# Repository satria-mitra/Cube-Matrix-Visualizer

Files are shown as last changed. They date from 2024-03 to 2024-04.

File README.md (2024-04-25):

# Cube-Matrix Visualizer

<p align="center">
  
</p>

To see how Cube Matrix works, please visit our [youtube channel](https://www.youtube.com/watch?v=XeQNfcWp1Bc)

## What is Cube-Matrix Visualizer?

Cube-Matrix Visualizer creatively connects the fields of IoT (Internet of Things) technology and art, aiming to create a data visualization device that meets the complex needs of contemporary society. Currently, the device focuses on reacting to changes in humidity, temperature and carbon dioxide concentration with a series of artistic LED animations. In the future, the team will provide OTA (over-the-air) services to upgrade the functionality of the device and enable broader data visualization through more captivating animations.

## Why is Cube-Matrix Visualizer Useful? 

In an era oversaturated with data, the Cube-Matrix Visualizer emerges as a beacon of innovation, merging the practicality of IoT technology with the sublime beauty of art. This fusion presents a unique advantage: making data not only accessible but also aesthetically pleasing, transforming mundane statistics into captivating visual stories.

### Artistry and Technology Combined

The Cube-Matrix Visualizer stands apart through its artistic approach to data visualization. Each LED animation is meticulously crafted, not just for clarity, but to evoke emotion and appreciation for the beauty inherent in data. The device acts as a living canvas, where pixels of light paint the ever-changing tapestry of our environment's data.

### Tailored to the Modern Aesthetic

Designed with modern sensibilities in mind, the Cube-Matrix Visualizer is more than a functional device—it's a piece of art that complements any space. Its sleek design and dynamic visual output offer a dual function: enhancing room aesthetics while providing valuable environmental insights. It's an innovative way to integrate technology into our lives without sacrificing style or comfort.

### Engaging Visual Experience

Beyond mere decoration, the Cube-Matrix Visualizer engages its users on a sensory level. The visualizations are designed not only to inform but to mesmerize, creating an immersive experience that turns data observation into a moment of zen. It encourages users to interact with and reflect on their environmental conditions, fostering a deeper connection between the user and their surroundings.

### A Canvas for Future Possibilities

The promise of OTA updates opens a realm of future possibilities, where the device's artistry and functionality evolve together. New data visualizations can be introduced, offering fresh perspectives and insights, and keeping the user's experience vibrant and current. This commitment to growth ensures that the Cube-Matrix Visualizer remains not only a tool for today but a lasting piece of art that continues to enrich lives.

## Market analysis

We are a small independent entrepreneurial company. Our product is an LED cube system that can visualize the air quality data (including CO2 concentration, temperature, humidity) collected by the sensor using an animation played by the LED cube.  This system uses an independent power supply and a wide voltage design, and can be used directly in most areas of the world. Users can use the buttons on the product base to switch animation modes and display different data. The cost of our product, without taking into account labor costs, is 126 pounds. It takes 24 hours of work for this team member to complete this product. If you consider London wage standards, the total cost is approximately 366 pounds, which is what we need solved problem.
Our target market is technology enthusiasts, education fields, and high-consumption groups. Our products will be crowdfunded on kickstarter.
Our opponents mainly fall into two categories. One is traditional LED cube kits, which are cheaper but cannot provide air quality detection functions. At the same time, they rarely sell finished products, which poses challenges to users’ technical capabilities and time. In addition, such products do not have the ability to interact with users. The other category is traditional air quality detectors, with similar accuracy, they are also cheaper, but they do not have furniture/decoration capabilities and lack the artistic expression of this product.
We will also provide free ota services to crowdfunding users to ensure the rights and interests of crowdfunding users.
Our current market areas are Europe and North America.

### SWOT.
- Advantage
LED CUBE with integrated air quality detection is a pioneering solution in the technology market, offering the dual functionality of air quality detection and visual display via an LED cube. This fusion of innovations not only differentiates the product but also captures a niche market consisting of technology enthusiasts, the education sector and high-spending groups. A significant advantage of this product is that users can interact with the product by changing animation modes and displaying various data, thus enhancing the overall user experience. Additionally, providing over-the-air (OTA) updates to crowdfunding users signifies our commitment to product longevity and customer satisfaction.

- Weakness
Conversely, the product's market penetration may be hampered by its high production costs (approximately £366), placing it in a higher price range, which may limit its acceptance by a wider audience. The production process for each unit requires 24 hours of labor, which not only drives up costs and selling prices, but also cuts production capacity. Furthermore, relying on crowdfunding to enter the market creates financial uncertainty, as access to funds in this way depends on the dynamics of crowdfunding platforms and investor interest.

- Opportunities
As people's living standards improve, people's awareness and concern about air quality in residential and office environments continues to grow, providing important opportunities for market expansion. By finding foundries to reduce costs and selling prices, and upgrading product features, these measures will tap a wider audience and stimulate market growth. Strategic alliances with educational institutions or environmental organizations can open up new avenues of market penetration and enhance brand credibility.

- Threaten
Although this product has good prospects, it still faces severe competition. These threats come from traditional LED cube kits and air quality detectors, which despite their limited functionality compared to the author's team's products, appeal to consumers through lower prices. Additionally, there is a risk that a saturation of similar products with imitators may dilute the uniqueness of the product. Economic fluctuations further exacerbate these threats, as a recession may reduce the disposable income of high-spending groups and reduce their interest in purchasing such products.

In addition, this group introduces value chain analysis here. Through the exploration of main activities and supporting activities, this analysis describes how to add value and minimize costs, thereby enhancing the product's competitive advantage in the global market.

### Main activities
-Inbound logistics
The initial stage of the value creation process: procuring high-quality sensors and LEDs from reputable suppliers to ensure product quality. At the same time, efficient inventory management is required to minimize storage costs and avoid stock-outs, thereby maintaining a seamless production process.

-Operations
The assembly of the LED cube system is a critical operation. The development of custom firmware for animated data display is at the heart of the product's uniqueness. Strict quality assurance processes are also implemented to meet the safety and performance standards of the regions in which they are sold.

-Outbound logistics
Strategic packaging of products not only ensures their protection during transportation, but also focuses on an environmentally friendly ethos. Logistics partners are selected with a focus on reliability and cost-effectiveness to facilitate global delivery capabilities.

-Marketing and Sales
Use social media, technology blogs and online forums to engage digital marketing strategies to attract the interest of technology enthusiasts and the education sector. Prepare your Kickstarter campaign carefully, aiming to emphasize the product's unique value proposition while seeking partnerships with educational institutions and environmental organizations to increase awareness of the product.

-Serve
Increase customer satisfaction and product longevity by providing after-sales support with comprehensive customer service for setup, usage and troubleshooting, as well as OTA updates for firmware enhancements and feature additions.

### Support activities
-Purchase
Negotiations with suppliers have a dual goal: to secure the best price without compromising quality, and to work with suppliers who can support scalable solutions as volumes increase.

-Technology development
The commitment to ongoing research and development is evident, with the goals of improving product performance, reducing production costs and incubating new features. Software development investments are aimed at refining the user interface and expanding functionality.

-Human resource Management
We are committed to training our teams in efficient production techniques and exemplary customer service, cultivating a culture full of innovation and continuous improvement.

-Infrastructure
The management of the overall operating structure focuses on financial management, legal support and administrative functions. We envisioned a scalable infrastructure capable of adapting to growing business needs, such as flexible IT systems and workspaces.

### Identify areas for improvement and cost reduction
Operational efficiency is targeted to improve, with potential strategies including automation and improved assembly techniques to reduce significant production time. Production scaling is considered a means to exploit economies of scale, thereby reducing unit costs and enhancing market competitiveness. Diversification of the supplier base is recommended to reduce risk and possibly cost through competitive sourcing. In addition, digital marketing efforts will be strengthened to use analytics as a tool to increase focus on ideal customer segments to optimize conversion rates.

## Getting Started

The Cube-Matrix Visualizer is available as a finished product. To get started:

1. Place an order and inspect the product upon arrival to ensure it's in good condition.
2. Connect the device to a power source. It's designed to support a wide range of voltages, making it accessible to users in various locations without the need for additional transformers. However, users with specific electricity requirements should use appropriate converters.
3. Once powered, the Cube will activate. Please allow a brief period for its sensors to adjust to optimal working conditions.
4. To cycle through different LED animations, simply press the button located on the front base of the device. Animations will change in sequence.

Now, you can assemble your own Cube-Matrix. To make your own cube, please follow the steps below:

1. Clone the Repository: git clone https://github.com/satria-mitra/Cube-Matrix.git
2. Hardware Setup: Assemble the Cube Matrix using the provided list of components and assembly instructions found in the Hardware folder.
3. Software Configuration: Navigate to the Software folder and follow the setup instructions to install necessary libraries and upload the code to your microcontroller.
4. Running Cube Matrix: Power up the device and use the button interface to toggle between different environmental data visualizations.

**Cube making steps**  
1. Use 3D printer to print two solder holders（solder holders/Holder-3.stl）.
   微信图片_20240424061742
3. Splice the two holders together, place the rgb LED on the holder and solder the data pin (data in to data out) between the two LEDs.
   LED schematic
4. Cut and straighten the copper wire and place the copper wire on the groove of the holder,then solder rgb led and copper wires according to the schematic diagram to make eight led layers, and power up to test each layer.
   微信图片_20240424062415
6. Laser cut four cube holders, then use the holders to support the layers to build the cube and solder the ground, power and data pins for each layer（Pay attention to the data pin connection method of each layer, data in must be connected to data out.）.
   微信图片_20240424062532
8. Use Adafruit Feather M0 Doard to connect the cube, connect the ground and power supply normally, and connect the data in of the bottom layer to the D6 pin of the board.
9. Upload the (Scripts/Final_code/Cube_Final.ino)code to the board, and the cube will display three animations in a loop.

## Getting Help

Owners of the Cube-Matrix Visualizer will receive a comprehensive manual detailing operational guidance and troubleshooting tips. Further assistance is available through several channels:

- **Email Support:** For direct inquiries, contact our customer service at Cube-Matrix-Visualizer@gmail.com.
- **GitHub Repository:** Feel free to post questions or feedback in the issues section of our GitHub repository.
- **Future Online Support:** We plan to launch a dedicated website offering an enhanced support function for an improved user experience.

For more direct assistance, you can also reach out to our team members via GitHub profiles linked in the Contributors section

## Contributors
Cube Matrix is maintained and contributed to by a dedicated team of students from the Connected Environments course at CASA. Our team members are
1. [Satria Utama ](https://github.com/satria-mitra)
2. [Guandi Chen](https://github.com/grandy0831)
3. [Huanchao Hong](https://github.com/ChaceHH-H)
4. [Zekun Wang](https://github.com/AntiRain114)

## Design, Development, and Execution
The Cube Matrix project started as an inspiration from a basic LED cube project, evolving into a sophisticated tool for visualizing environmental quality. The project's development journey, from the initial 5x5x5 cube prototype to the advanced 8x8x8 design, showcases our commitment to innovation and user-centric design.  

## Key Features
Environmental Monitoring: Measures temperature, humidity, and CO2 levels.
Dynamic Visual Display: Uses animations to display IEQ data, making it intuitive.
Educational Tool: Helps users understand the impact of IEQ on health and well-being.
For a comprehensive overview of the design process, technical challenges, and our solutions, please refer to the Documentation folder, which includes detailed design documents and technical drawings.

## License
This project is licensed under the MIT License - see the LICENSE file for details.

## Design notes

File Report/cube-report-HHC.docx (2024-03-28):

原计划的缺点

（原计划led的图片）

（原计划动画的设计图片）

We showed our initial plan at the first Group Crit, using common anode RGB LEDs to make a 5*5*5 RGB cube, using SCD-30 to read three kinds of data, and use one animation to display the temperature, humidity and CO2 data at the same time. The week after Group Crit we tried making and soldering some LEDs, but then we discovered the disadvantages of using common anode RGB LEDs: The common anode RGB LED uses three GPIO pins to control the brightness of red, green, and blue colors. This means that if we want to individually control the color of each LED in the cube, each LED requires three motherboard GPIO pins. So we must use additional hardware (such as shift registers or LED drivers) to expand the GPIO pins. Even a small cube of 5*5*5 will require dozens of registers and hundreds of resistors, which will cause Circuit design has become very complicated, whether it is LED welding or PCB design, it is not an easy task. And we also found the 5*5*5 cube to be too small at 125 LEDs, which limits the level of detail in the animation that the cube can show, and fewer LEDs means that fewer pixel points are changing at any given time, which can result in animations that don't look smooth or coherent. Less 3D space is provided, which limits creativity in spatial animation.

计划变动

（APA106 pin脚图片）

So after careful consideration, we changed our plan during reading week. Our new plan use APA106, which is addressable RGB LED with built-in controller IC and register, each LED only need one wire to connect data in pin to motherboard GPIO pin to control the colour, so we don't need any register and other Components, compared to common RGB LEDs, it is much easier to use and build, greatly simplifying the circuit, we only use three jumpers to control hundreds of rgb led, and also allows us to easily build larger rgb cube.

In addition, we upgraded the cube to 8*8*8, using 512 LEDs, compared to 5x5x5 with 125 LEDs, which can display more complex and detailed images and animations, providing a richer visual experience. The larger 3D space allows for more complex animation effects to be achieved in a three-dimensional space. This increased spatial dimension provides more possibilities for designing animations that allow for more animation effects to be explored with respect to light and shadow, depth and perspective. The new plan changed from showing three pieces of data in one animation to designing a separate animation for each piece of data, as we found that showing three pieces of data at the same time would make it difficult to understand and get the visualisation of the data from the animation.

制作步骤

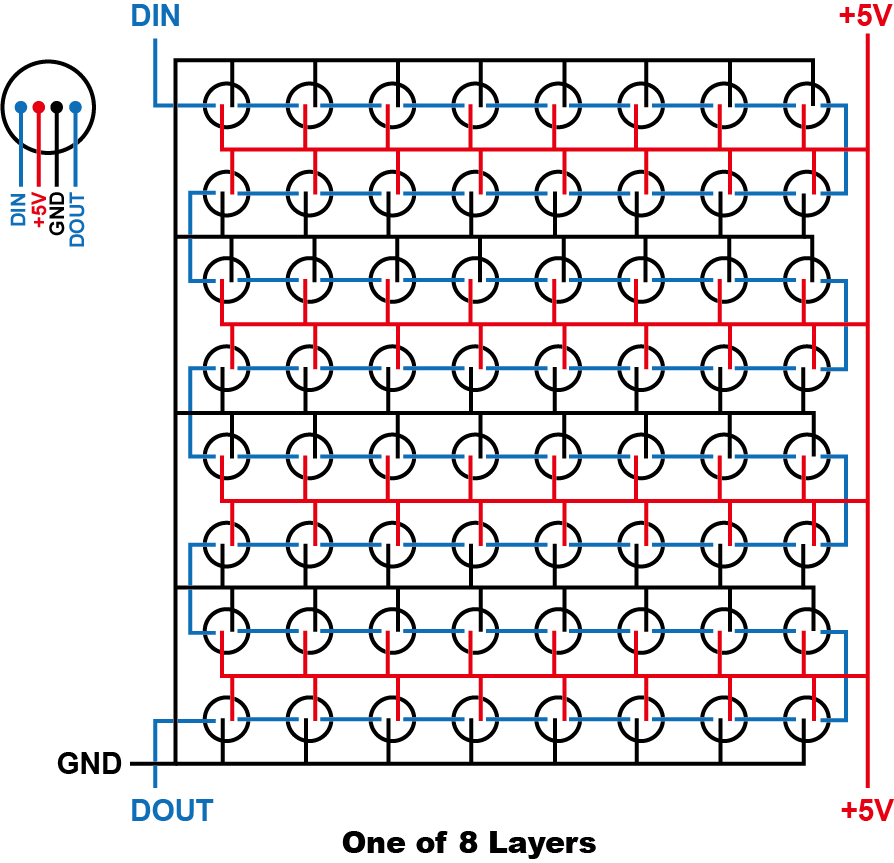
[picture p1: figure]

We first designed the wiring of the cube, our design is to divide the cube into eight 8*8 led layers, each layer is actually a strip of 64 leds as shown in the figure, because the APA106 has a built-in controller IC and uses the same protocol as the WS28 LEDs, we can make it an rgb strip by connecting the data of the previous led data out to the data in of the next led to connect the led in series and make it a rgb strip. As shown in the picture, the blue line is the data pin which connects all the LEDs in series, the black and red lines are the ground and power supply, all the LEDs share the ground and power supply.

（holder 的图片）

Next we weld layer, in order to ensure that the welding neat and beautiful, we first 3d printed 3 welding holder, holder on the holes reserved for placing the led and wire, we first put the leds into the holes, will be welded in series with the led's data pin, and then use the straightened copper wire as the power rail welding grounding and power supply.

（layer通电的图片）

We soldered 8layers and powered up to check if eachlayer is soldered correctly, tested to control the rgb colour using the test code, the APA106 supports the same protocol as the WS28 LEDs, so we used Adafruit_NeoMatrix and NeoPixel to control the colour and brightness of the led.

（cube图片）

After soldering eight layers, we stacked the layers on top of each other and soldered the data pins between them to make the layers into a long strip of 512 leds, which of course look like cubes in appearance. we used the SCD-30 to take readings of temperature, humidity and co2 and connected the sensors and the cube to the feather M0 board.

代码

After completing the cube assembly, we started writing the animation code. Since the cube is actually a strip of lights on the circuit connections, we use the Adafruit_NeoMatrix library to simulate the led strip as a cube, this will reassign the coordinates of the leds and allowing us to write the animation more easily, and then use the Adafruit_NeoPixel library to control the led colours.

（led函数图片）

There are a couple of key functions in the code, one for lighting up the led, led() takes the coordinates and colours it receives and then uses NeoPixel library commands to control the lighting of the led.

（color数组和函数图片）

We put the rgb values of commonly used colours into the color array to be used to change colours more easily. When used, the GetColor() function assigns the rgb values to the NeoPixel library colour command.

（按钮函数）

Our cube has a button to toggle the animation, and the button is called using attachInterrupt() so that the button can be detected in real time while the animation function is running, and all the animation functions will detect when the button's state changes by checking to see if the button is break; or return;, to skip the rest of the function that is not executed in order to to toggle the animation on-the-fly.

We have four animation functions, three for data visualisation and one for numeric and alphabetic animation to display the data. The code structure of the animation functions is actually quite simple, we make extensive use of for and while statements, and use the led() function in a loop to change the coordinates and colour of the lit led to compose the animation. The most difficult part was designing the coordinates of the led in each loop, and we spent a lot of time testing and envisioning the logic of the led changes.

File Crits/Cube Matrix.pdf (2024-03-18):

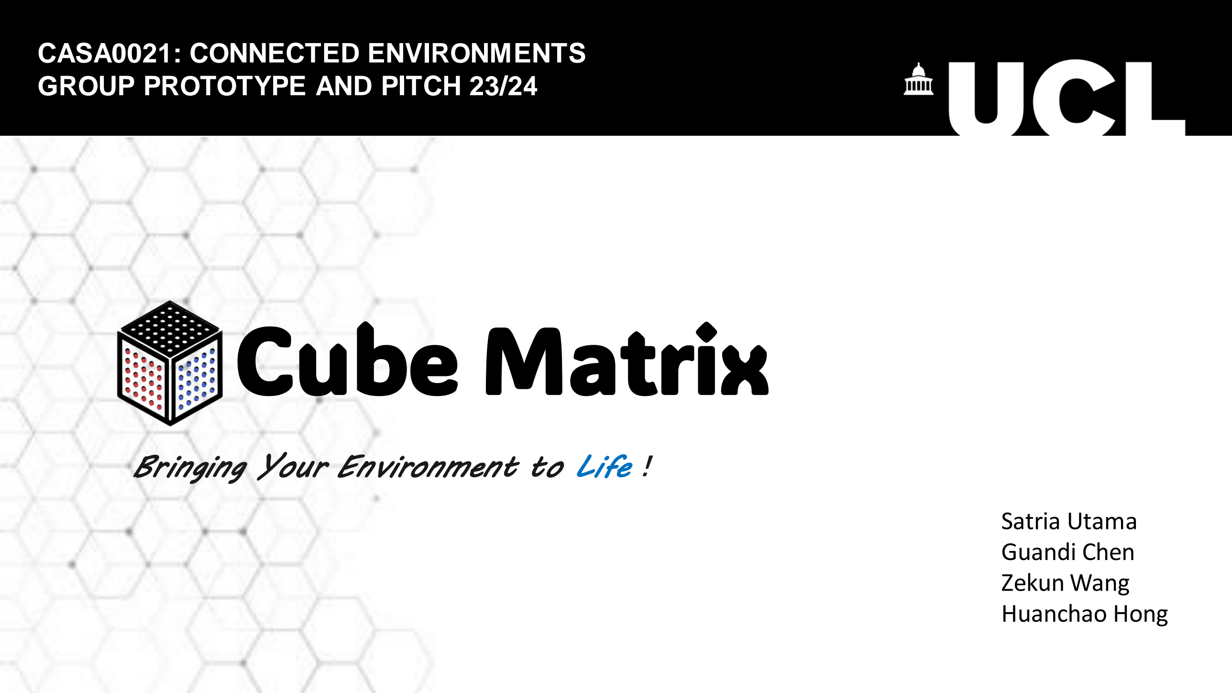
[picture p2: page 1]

# Cube Matrix

Bringing Your Environment to Life！

Satria Utama
Guandi Chen
Zekun Wang
Huanchao Hong

CASA0021: CONNECTED ENVIRONMENTS GROUP PROTOTYPE AND PITCH 23/24

# Team Members

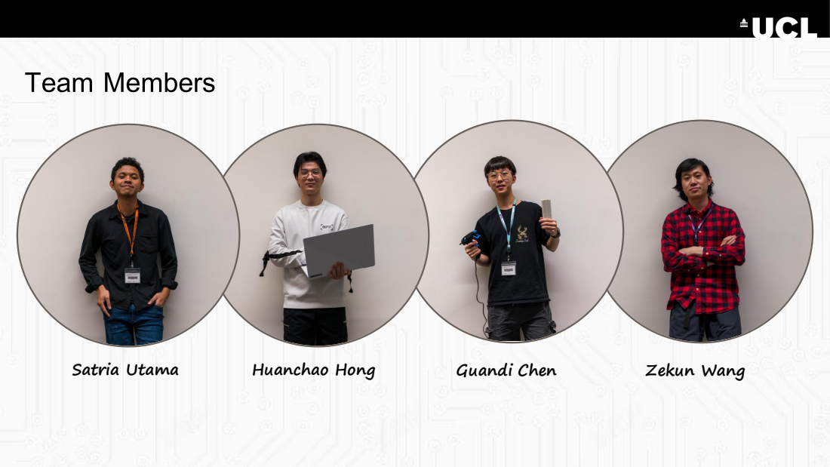
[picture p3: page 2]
Satria Utama; Huanchao Hong; Guandi Chen; Zekun Wang

# Background

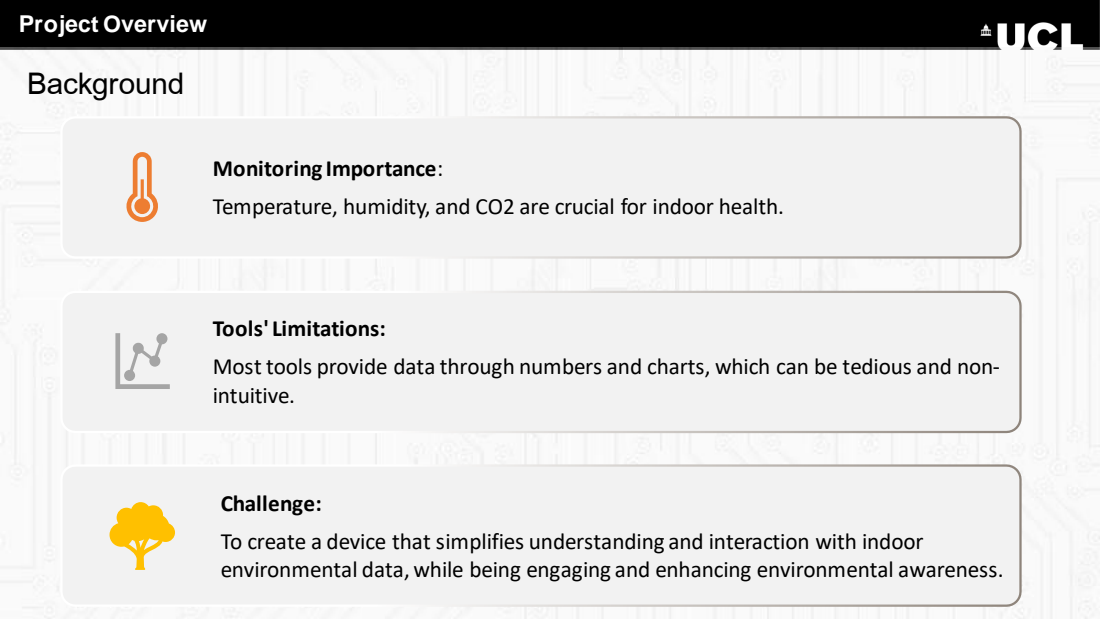
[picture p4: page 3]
Project Overview

Monitoring Importance:
Temperature, humidity, and CO2 are crucial for indoor health.

Tools' Limitations:
Most tools provide data through numbers and charts, which can be tedious and non-
intuitive.

Challenge:
To create a device that simplifies understanding and interaction with indoor
environmental data, while being engaging and enhancing environmental awareness.

# Solution: Cube Matrix

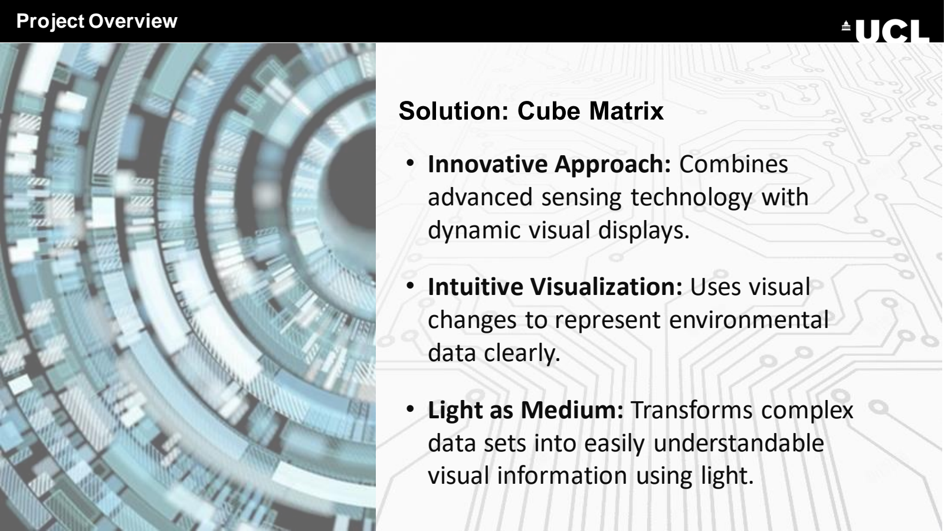
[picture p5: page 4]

- Innovative Approach: Combines advanced sensing technology with dynamic visual displays.
- Intuitive Visualization: Uses visual changes to represent environmental data clearly.
- Light as Medium: Transforms complex data sets into easily understandable visual information using light.

Project Overview

Promotional video

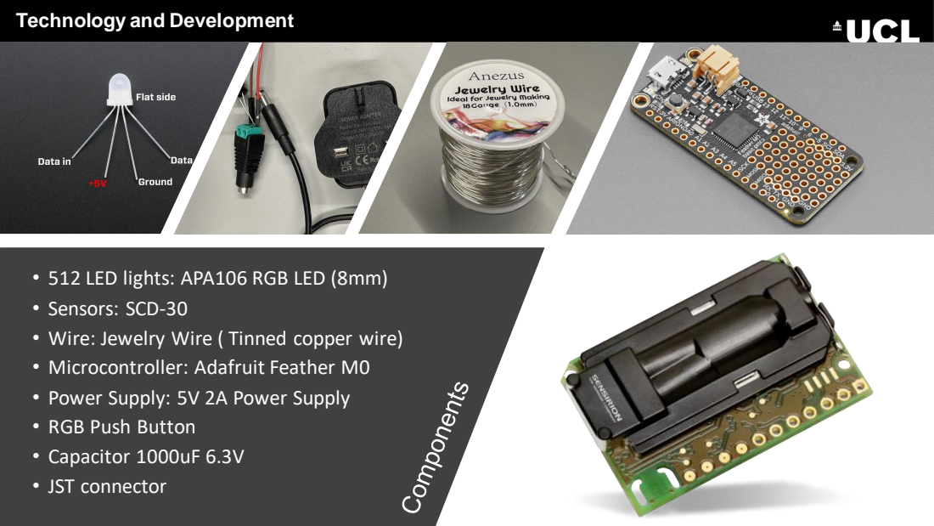
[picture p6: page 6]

Technology and Development

• 512 LED lights: APA106 RGB LED (8mm)
• Sensors: SCD-30
• Wire: Jewelry Wire ( Tinned copper wire)
• Microcontroller: Adafruit Feather M0
• Power Supply: 5V 2A Power Supply
• RGB Push Button
• Capacitor 1000uF 6.3V
• JST connector

# Evolution of the Idea

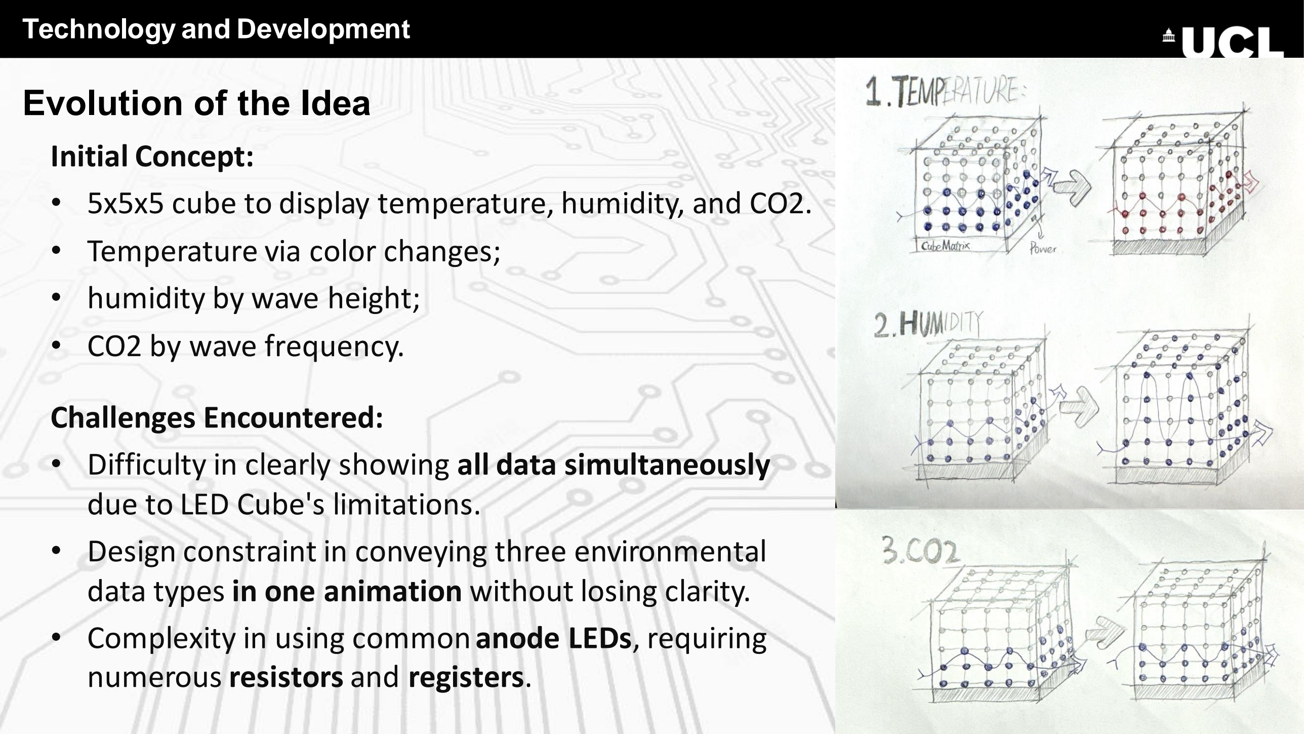
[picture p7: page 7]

Initial Concept:
- 5x5x5 cube to display temperature, humidity, and CO2.
- Temperature via color changes;
- humidity by wave height;
- CO2 by wave frequency.

Challenges Encountered:
- Difficulty in clearly showing all data simultaneously due to LED Cube's limitations.
- Design constraint in conveying three environmental data types in one animation without losing clarity.
- Complexity in using common anode LEDs, requiring numerous resistors and registers.

# Evolution of the Idea

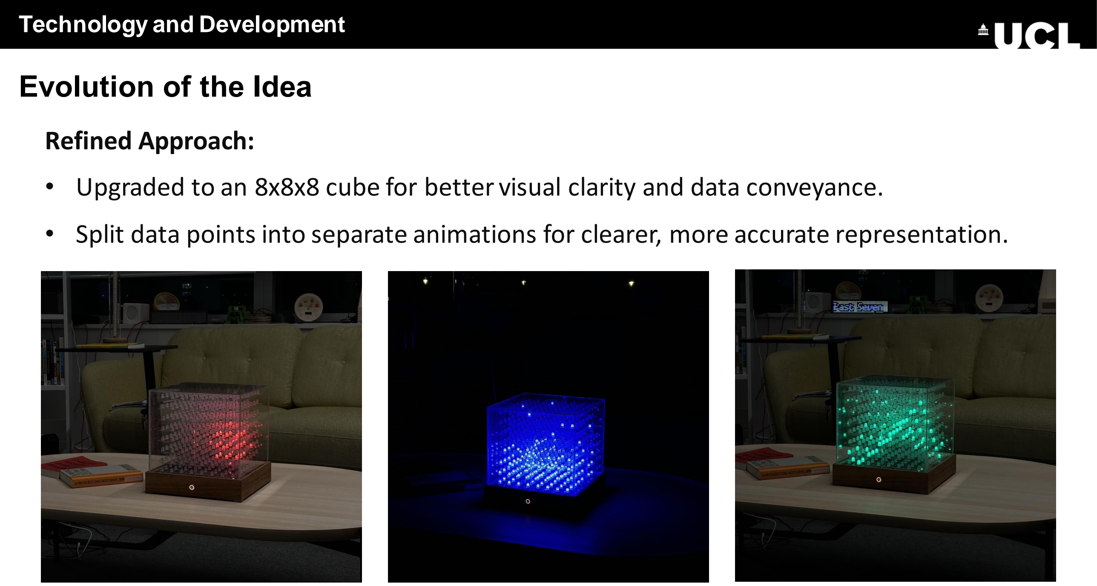
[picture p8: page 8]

Refined Approach:
- Upgraded to an 8x8x8 cube for better visual clarity and data conveyance.
- Split data points into separate animations for clearer, more accurate representation.

# LED lights:

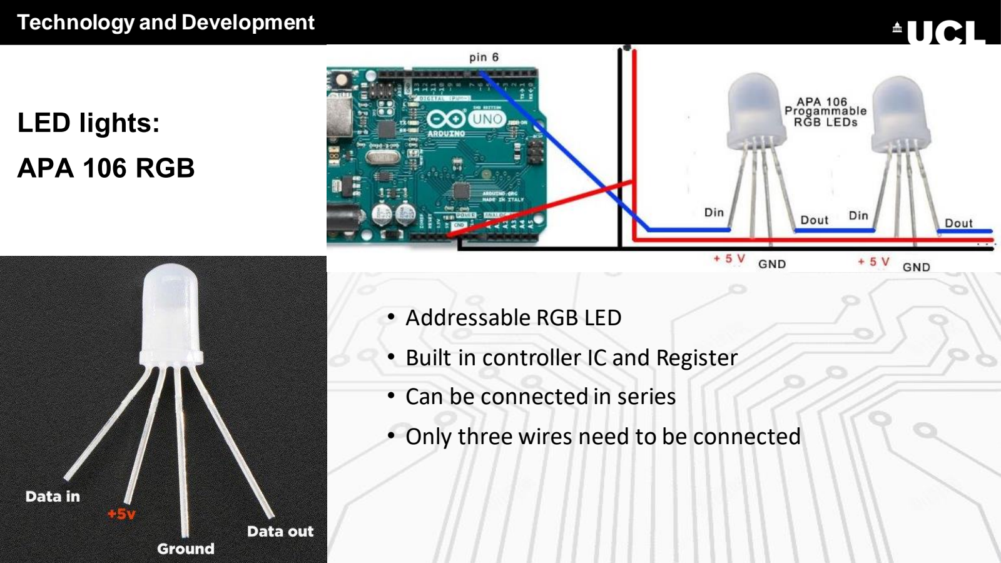
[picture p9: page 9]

# APA 106 RGB

- Addressable RGB LED
- Built in controller IC and Register
- Can be connected in series
- Only three wires need to be connected

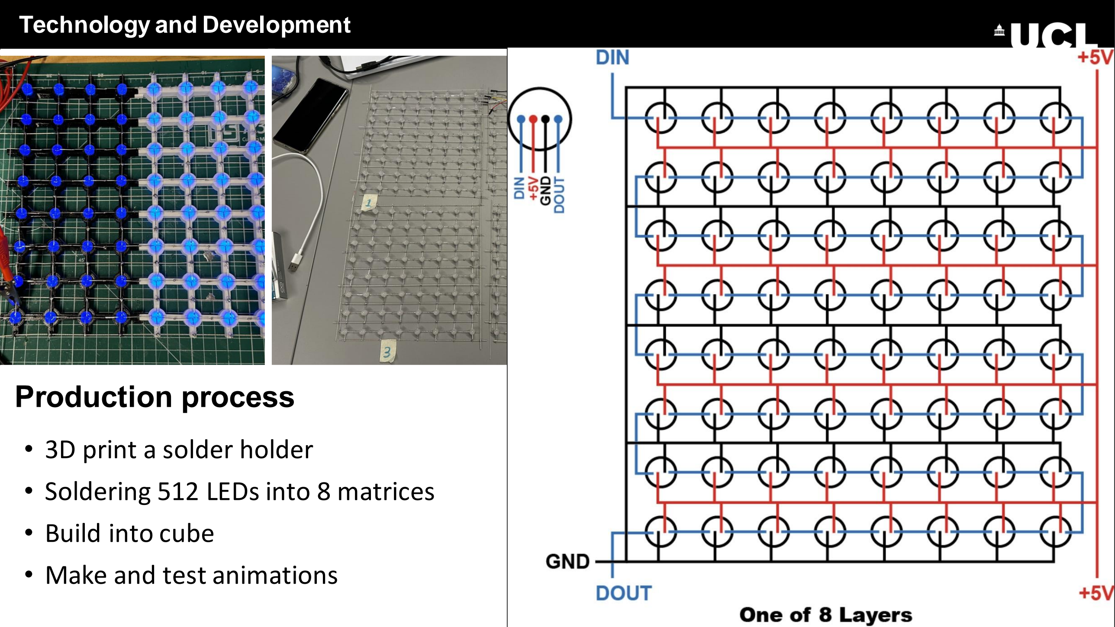
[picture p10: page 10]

# Productionprocess

- 3D print a solder holder
- Soldering 512 LEDs into 8 matrices
- Build into cube
- Make and test animations

# Temperature: Sun Ball Animation

- Color: from blue (cool) to red (warm) to show temperature.
- Speed: slow for cool, fast for warm.
- Connection: sun as a natural, intuitive temperature source.

# Humidity: Droplet Accumulation

- Layers of Accumulation: Water droplets accumulate in layers, each representing a 10% increase in humidity.
- This animation simplifies indoor humidity assessment and enhances data interaction.
- Connection: droplets as a direct manifestation of humidity.

- Color Coding: Color shifts from green (normal) to red (above 1500ppm) for CO2 levels.
- Frequency: low for normal, high indicates excess CO2.
- Connection: fluctuations can symbolize changes in air fluidity and quality.

CO2 :

# Wave Frequency

# Why Display Numerical Data?

- Provides precise measurements for detailed understanding.
- Balances intuitive animations with accurate data for diverse preferences.

# Advanced prototype

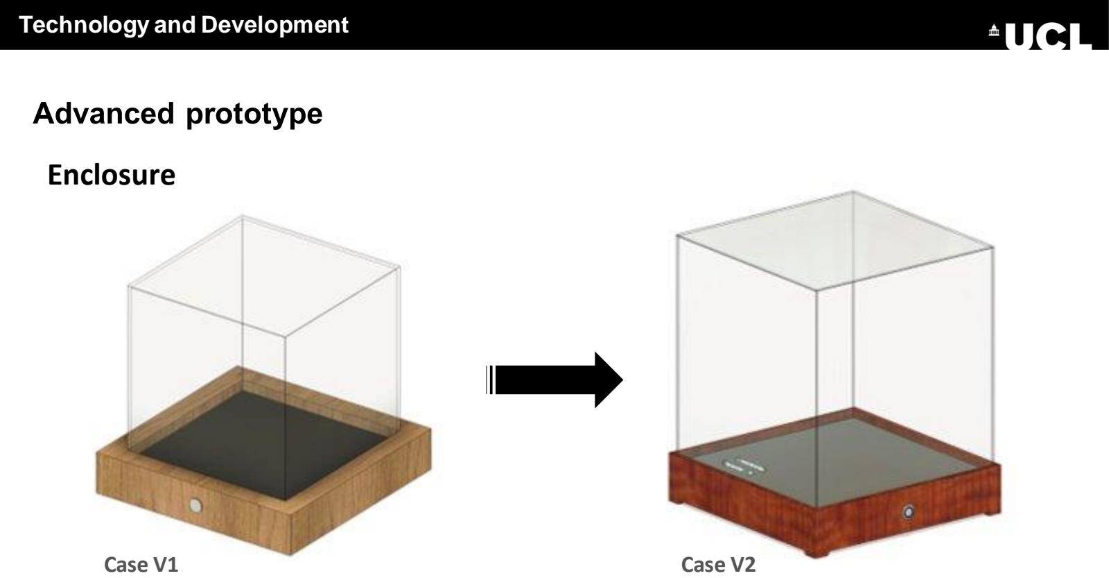
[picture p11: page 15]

Enclosure

Case V1 | Case V2

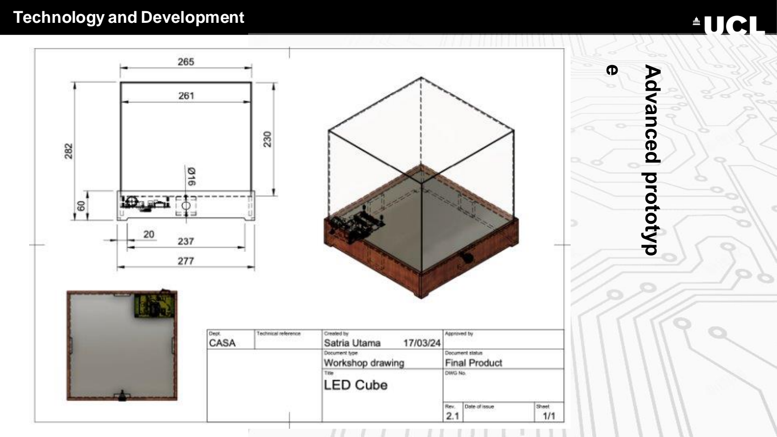
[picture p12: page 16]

# Advanced prototyp

e

# Advanced prototype

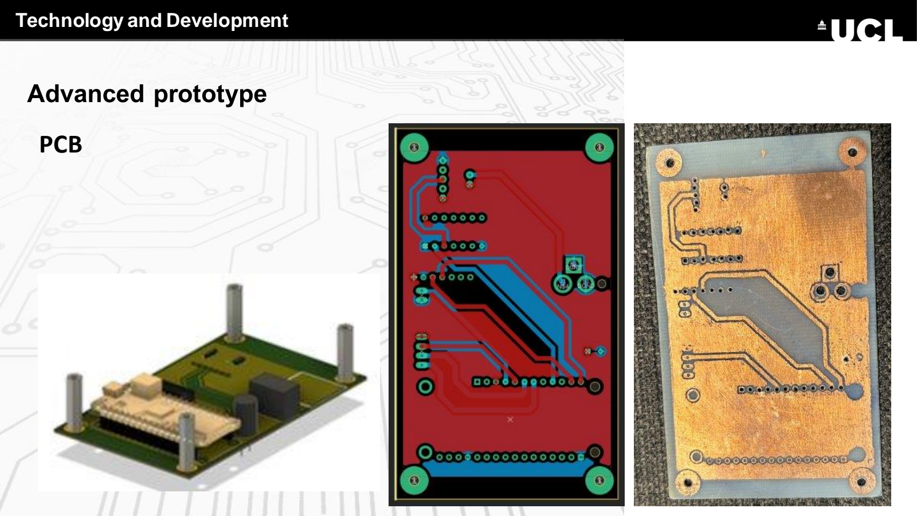
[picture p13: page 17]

PCB

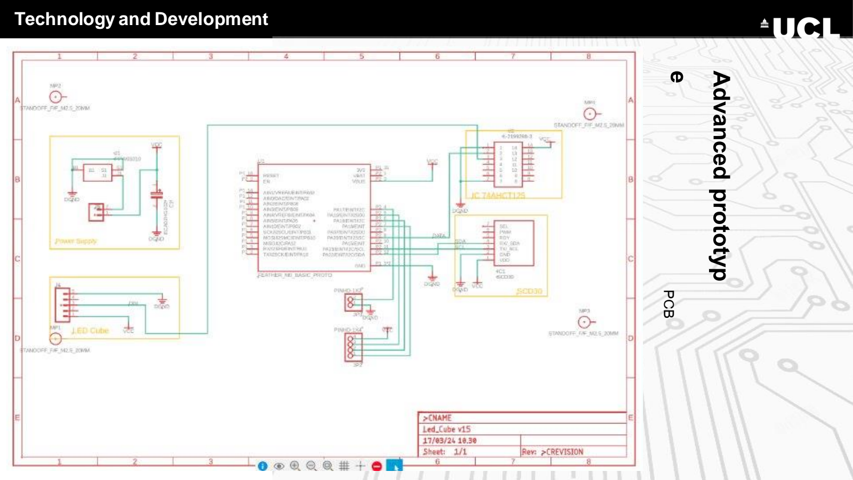
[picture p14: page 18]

# Advanced prototyp

# e PCB

Market Positioning

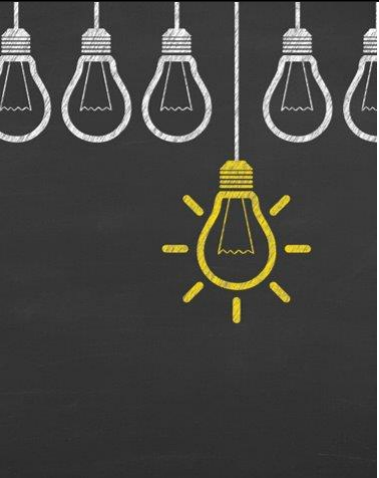
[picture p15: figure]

# Who Can Benefit from Cube Matrix?

Broad Appeal:
- Suitable for homeowners, schools, and offices for easy indoor environment monitoring. Educational Tool:
- Essential for teaching environmental science and raising awareness.
Health and Wellness:
- Beneficial for those focused on healthy indoor air quality and wellness.

# Comparison with Existing Solutions

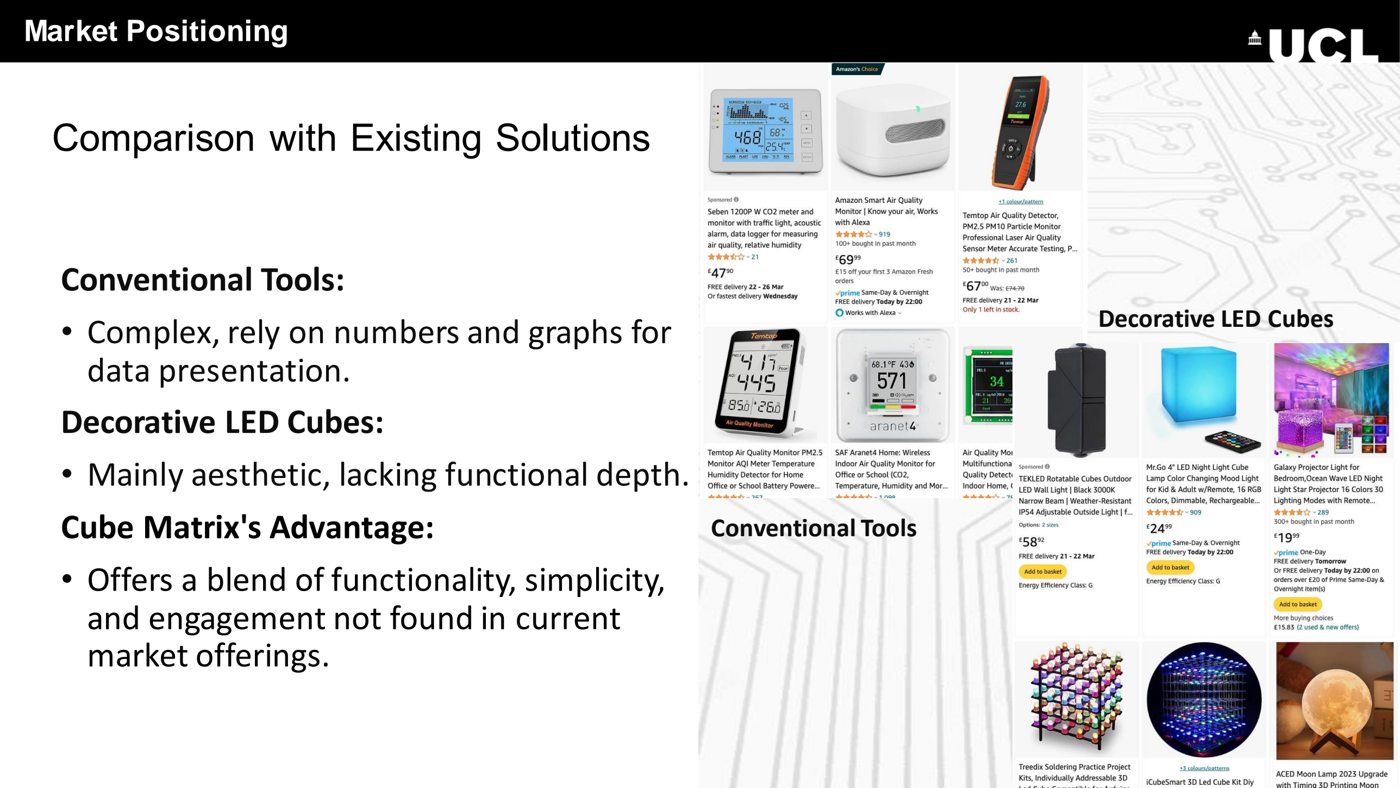
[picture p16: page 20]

Conventional Tools:
- Complex, rely on numbers and graphs for data presentation.
Decorative LED Cubes:
- Mainly aesthetic, lacking functional depth. Cube Matrix's Advantage:
- Offers a blend of functionality, simplicity, and engagement not found in current market offerings.

Market Positioning

Conventional Tools

Decorative LED Cubes

Challenges and Limitations

- Core Challenge: Merge temperature, humidity, CO2 into animations.
- Design Challenges: Address LED Cube's feasibility and coding.
- Cost & Manufacturing: Solve soldering errors and disconnections.
- Maintenance Challenges: Simplify maintenance and reduce damage risk.
- PCB

# Challenges and Limitations

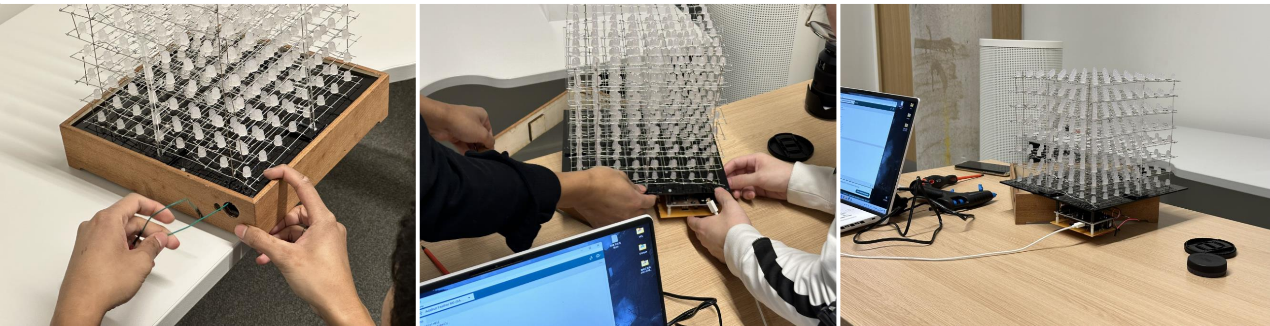
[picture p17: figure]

Future Improvement

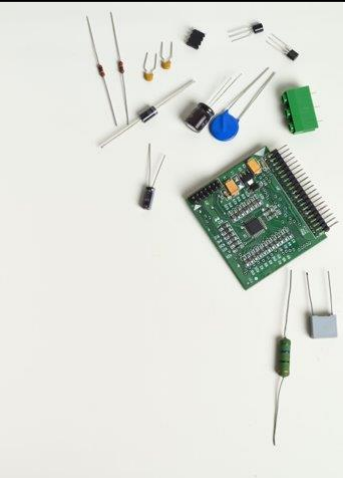
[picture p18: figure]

# Future Improvement Measures

### 1. Integration: Refine algorithms for smoother

animation data integration.

### 2. Design: Redesign Cube for simpler coding and better

interaction.

### 3. Manufacturing: Upgrade to professional welding

techniques and PCB.

### 4. Maintenance: Shift to modular design for

straightforward updates and repairs.

### 5. Data Points: Add air quality indices for broader

environmental tracking.

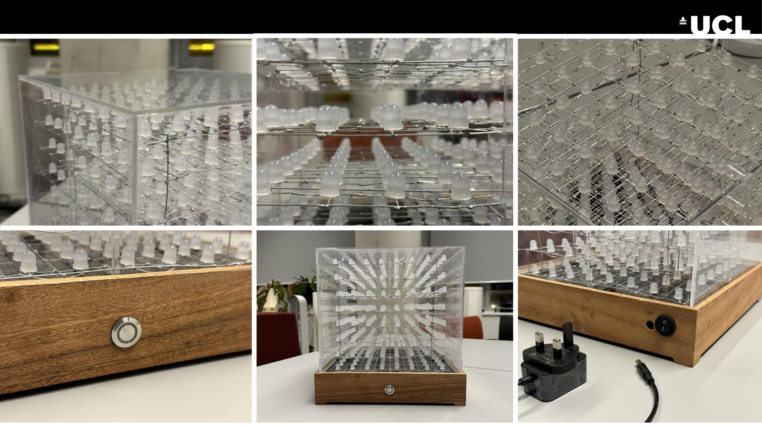
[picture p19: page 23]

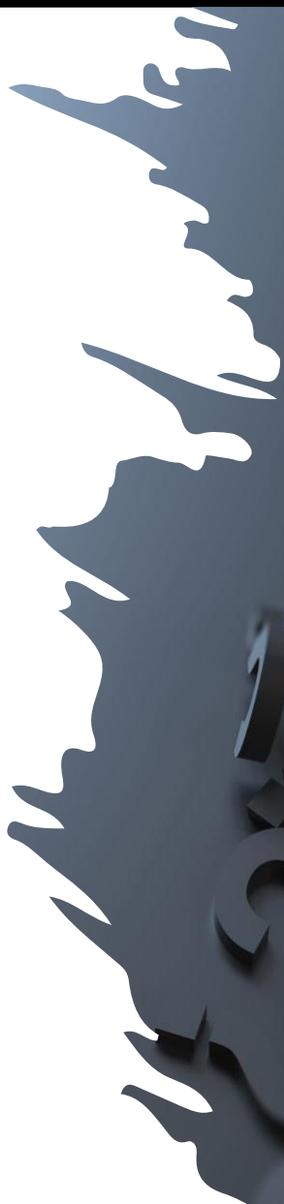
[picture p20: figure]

# Thank!

Q&A Session.

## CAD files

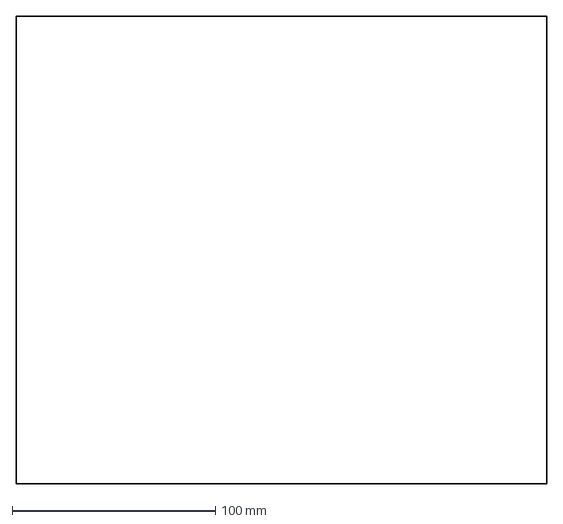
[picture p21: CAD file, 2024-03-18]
Components/Cutting parts/Acrylic/cover_acrylic_back.dxf
261.0 x 230.0 mm

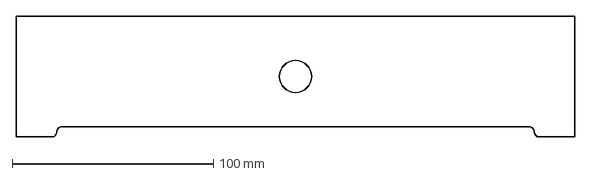
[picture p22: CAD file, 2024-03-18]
Components/Cutting parts/Wood Case/front_wood_case.dxf
277.0 x 60.0 mm

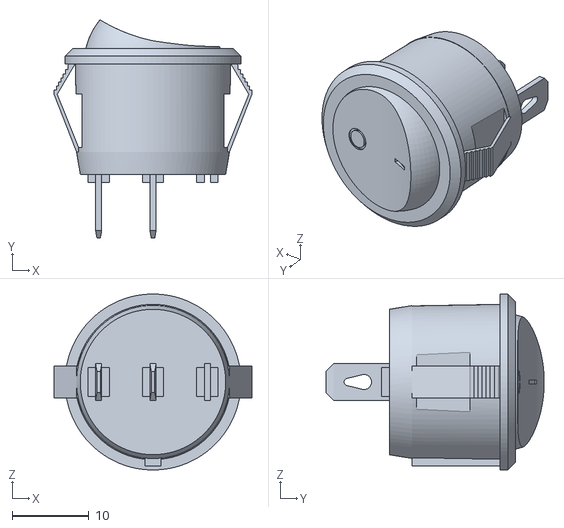
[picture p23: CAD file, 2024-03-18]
Components/Fusion 3D parts/Rocker Switch v1.obj
25.9 x 28.6 x 23.0

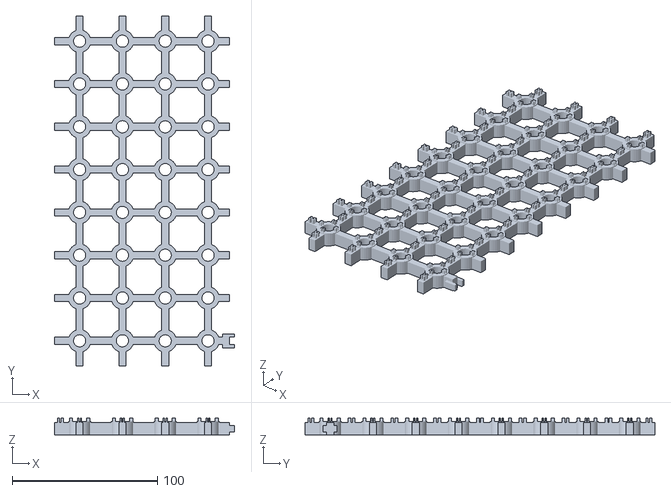
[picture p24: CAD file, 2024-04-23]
solder holders/Holder-3.stl
124.1 x 241.2 x 11.5

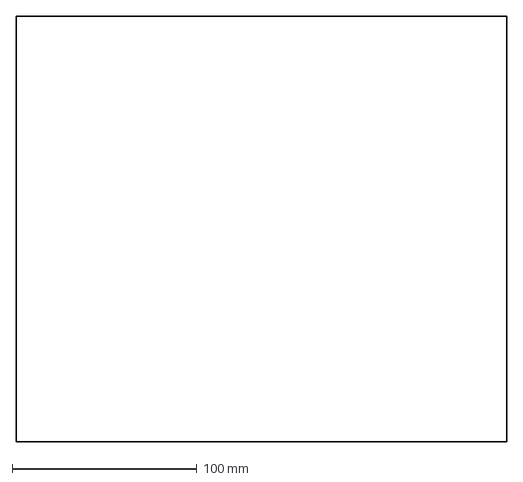
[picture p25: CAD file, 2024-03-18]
Components/Cutting parts/Acrylic/cover_acrylic_right.dxf
265.0 x 230.0 mm

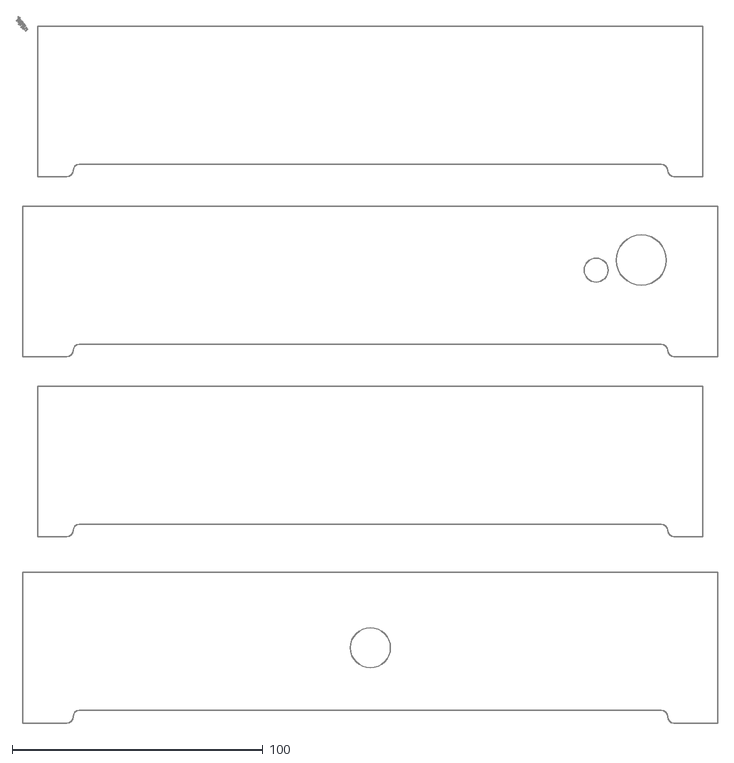
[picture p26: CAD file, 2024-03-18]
Components/Cutting parts/Wood Case/all_wood_case.dxf
279.7 x 281.8

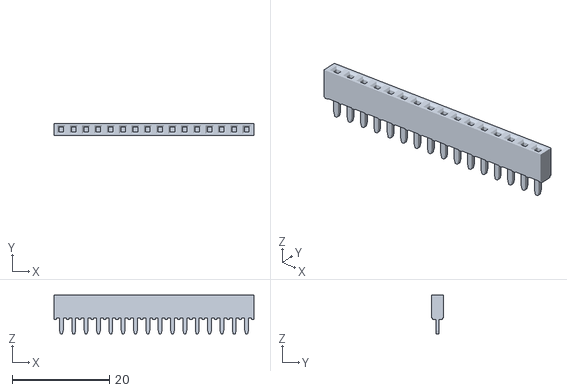
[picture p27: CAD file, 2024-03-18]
Components/Fusion 3D parts/16-Pin Header - Female - 2.54mm v1.obj
41.1 x 2.50 x 8.00

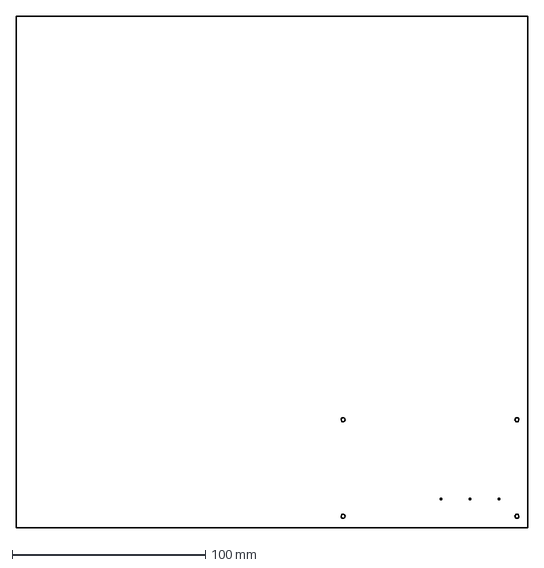
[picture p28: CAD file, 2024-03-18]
Components/Cutting parts/Acrylic/base_acrylic_black.dxf
265.0 x 265.0 mm

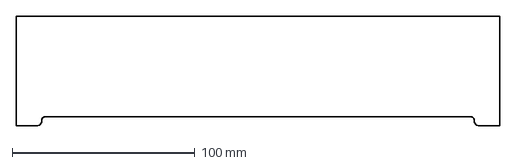
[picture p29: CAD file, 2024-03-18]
Components/Cutting parts/Wood Case/left_wood_case.dxf
265.0 x 60.0 mm

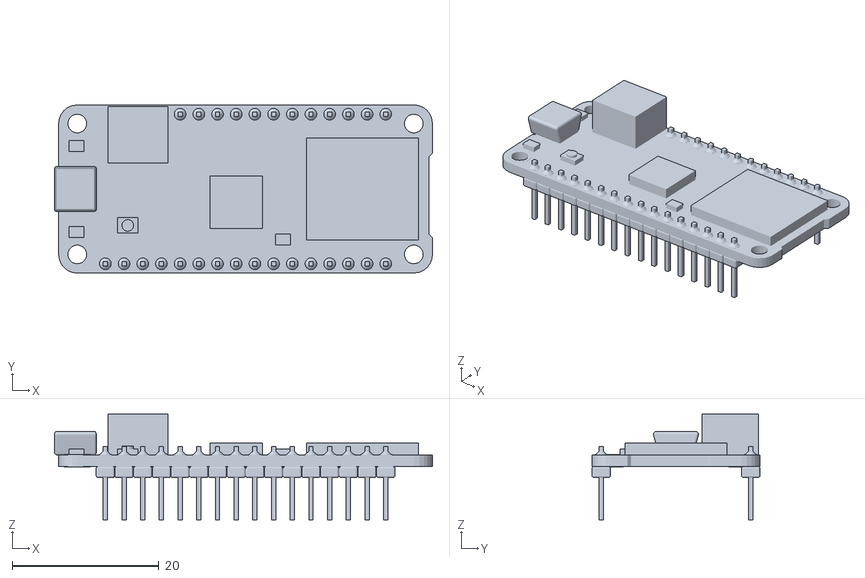
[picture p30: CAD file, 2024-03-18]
Components/Fusion 3D parts/FEATHER_M0_BASIC_PROTO v2.obj
51.6 x 22.9 x 14.5

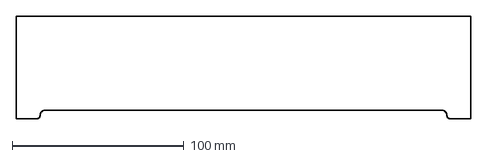
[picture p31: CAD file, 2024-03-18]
Components/Cutting parts/Wood Case/right_wood_case.dxf
265.0 x 60.0 mm

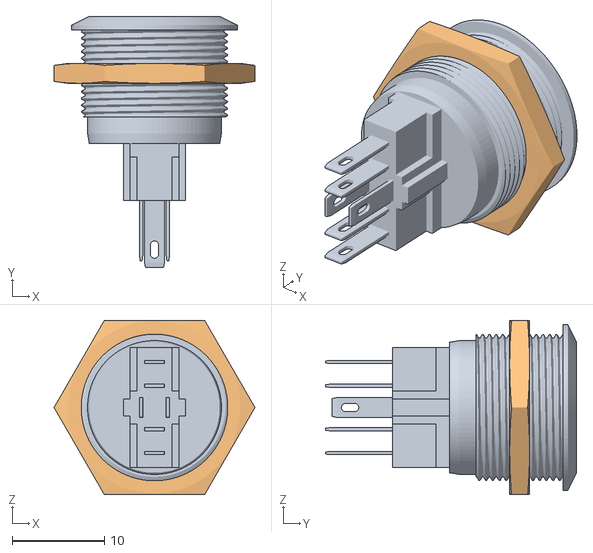
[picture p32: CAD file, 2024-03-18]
Components/Fusion 3D parts/RGB_push_button_16mm.obj
21.8 x 27.3 x 18.9

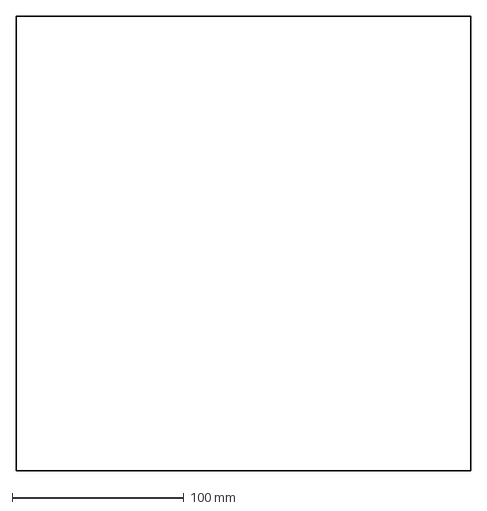
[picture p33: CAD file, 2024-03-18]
Components/Cutting parts/Acrylic/cover_acrylic_top.dxf
265.0 x 265.0 mm

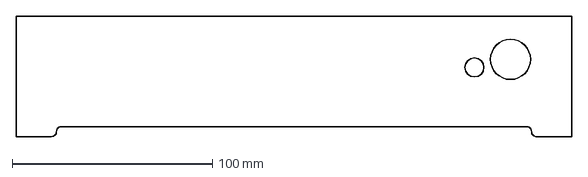
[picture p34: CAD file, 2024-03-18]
Components/Cutting parts/Wood Case/back_wood_case.dxf
277.0 x 60.0 mm

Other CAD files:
Components/Cutting parts/Acrylic/cover_acrylic_left.dxf
Components/Cutting parts/Acrylic/cover_acrylic_front.dxf

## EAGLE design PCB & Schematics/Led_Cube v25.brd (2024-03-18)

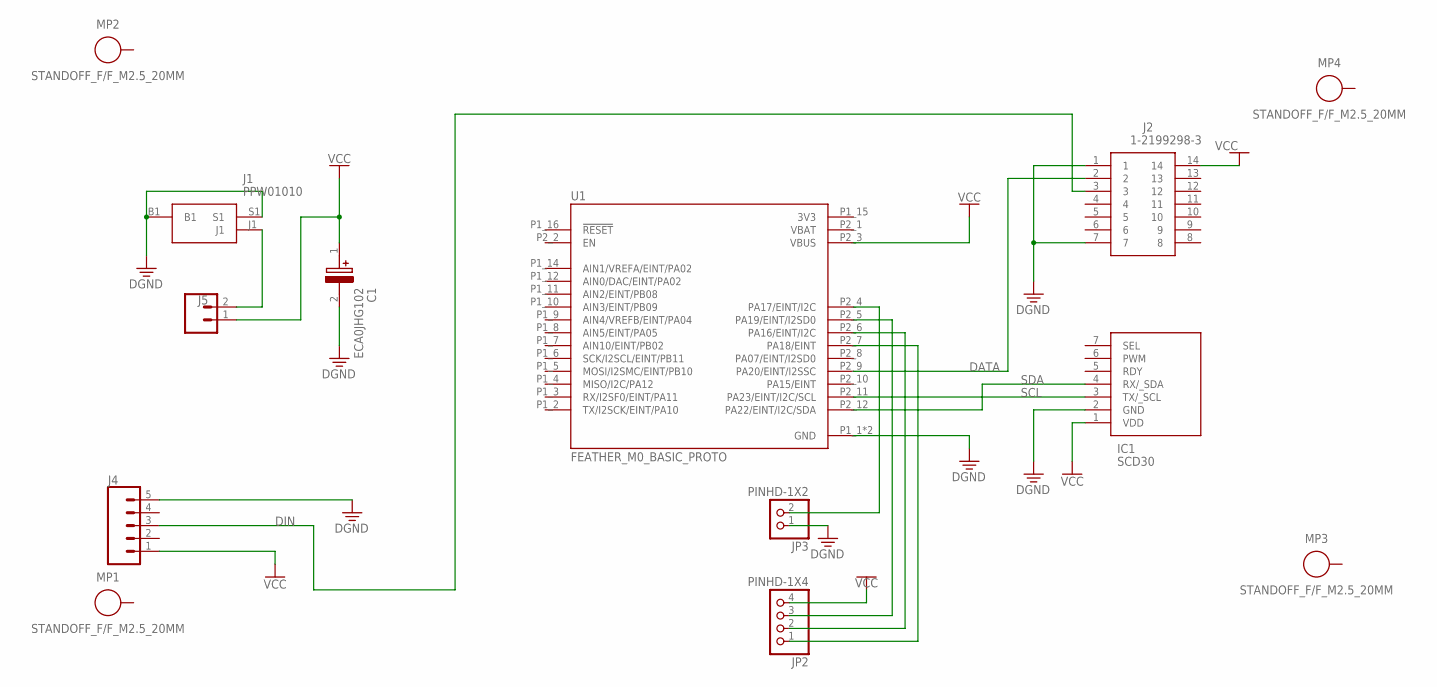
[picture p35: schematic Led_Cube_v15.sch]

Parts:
C1: ECA0JHG102; CAPPRD350W65D800H1250
IC1: SCD30
J1: PPW01010
J2: 1-2199298-3; DIPS762W70P254L1778H510Q14N
J4: CONN_05PTH; 1X05
J5: CONN_02; 1X02
JP2: PINHD-1X4; 1X04
JP3: PINHD-1X2; 1X02
MP1, MP2, MP3, MP4: STANDOFF_F/F_M2.5_20MM; STANDOFF_HEX_FEMALE_500X2000_M2.5X0.45_MTGP755H270
U1: FEATHER_M0_BASIC_PROTO; MODULE_FEATHER_M0_BASIC_PROTO

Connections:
3V3: U1.P1_15 (3V3)
BLUE: JP2.3, U1.P2_5 (PA19/EINT/I2SD0)
DATA: J2.2, U1.P2_9 (PA20/EINT/I2SSC)
DGND: C1.2 (-), IC1.2 (GND), J1.B1, J1.S1, J2.1, J2.7, J4.5, JP3.1, U1.P1_1 (GND), U1.P1_13 (GND)
DIN: J2.3, J4.3
GREEN: JP2.2, U1.P2_6 (PA16/EINT/I2C)
unnamed: J1.J1, J5.2
RED: JP2.1, U1.P2_7 (PA18/EINT)
SCL: IC1.3 (TX/_SCL), U1.P2_11 (PA23/EINT/I2C/SCL)
SDA: IC1.4 (RX/_SDA), U1.P2_12 (PA22/EINT/I2C/SDA)
SW1: JP3.2, U1.P2_4 (PA17/EINT/I2C)
VBAT: U1.P2_1 (VBAT)
VCC: C1.1 (+), IC1.1 (VDD), J2.14, J4.1, J5.1, JP2.4, U1.P2_3 (VBUS)

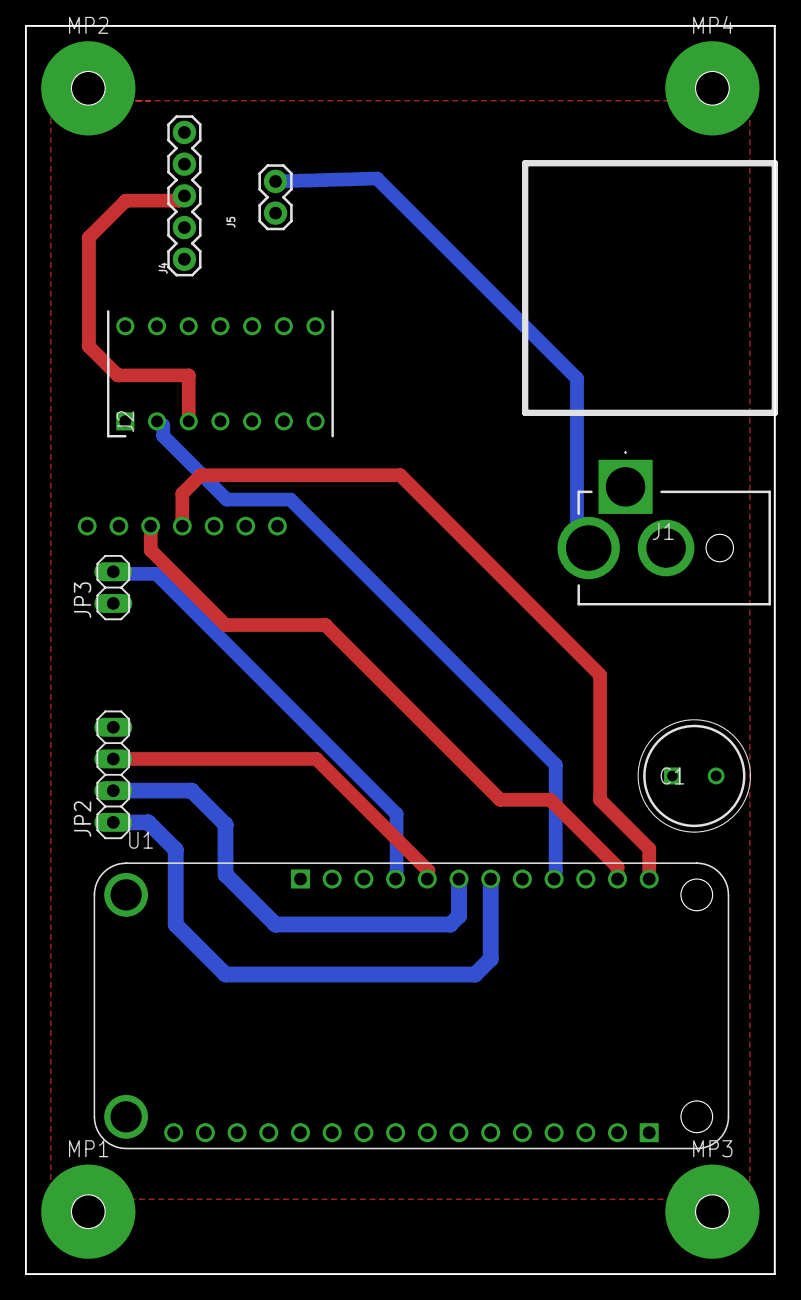
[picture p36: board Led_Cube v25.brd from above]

Board: 2 copper layers, 60.0 x 100.0 mm, 13 parts (1 on the bottom side), 11 nets.

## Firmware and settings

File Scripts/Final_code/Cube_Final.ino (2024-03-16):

#define myLayer 2
#include <Adafruit_GFX.h>
#include <Adafruit_NeoMatrix.h>
#include <Adafruit_NeoPixel.h>
#include <Wire.h>

#include <SparkFun_SCD30_Arduino_Library.h> // Include the SCD30 library
#define PIN 6
//////////////////////////////////

volatile uint16_t mymatrix[16][8];  // color of each LED in the matrix
int brightness = 80;  // set brightness
///Simulate LED light strip into cube
Adafruit_NeoMatrix cube = Adafruit_NeoMatrix(8, 8, 8, 1, PIN,
                          NEO_MATRIX_TOP     + NEO_MATRIX_LEFT +
                          NEO_MATRIX_COLUMNS + NEO_MATRIX_ZIGZAG,
                          NEO_RGB            + NEO_KHZ800);



#define White 43
#define Black 0
#define Red 1
#define Red2 44
#define Blue 45
#define Orange 4
#define Yellow 9
#define Green 15
#define Aqua 20
#define Blue 29
#define Purple 34
uint32_t mycolor;
const byte color [46][3] PROGMEM = {  // the color pallette table
  {0, 0, 0}, //Black
  {7, 0, 0}, {7, 1, 0}, {6, 1, 0}, {6, 2, 0}, {5, 2, 0}, {5, 3, 0}, {4, 3, 0}, {4, 4, 0}, {3, 4, 0}, {3, 5, 0}, {2, 5, 0}, {2, 6, 0}, {1, 6, 0}, {1, 7, 0}, // Red to Green
  {0, 7, 0}, {0, 7, 1}, {0, 6, 1}, {0, 6, 2}, {0, 5, 2}, {0, 5, 3}, {0, 4, 3}, {0, 4, 4}, {0, 3, 4}, {0, 3, 5}, {0, 2, 5}, {0, 2, 6}, {0, 1, 6}, {0, 1, 7}, // Green to Blue
  {0, 0, 7}, {1, 0, 7}, {1, 0, 6}, {2, 0, 6}, {2, 0, 5}, {3, 0, 5}, {3, 0, 4}, {4, 0, 4}, {4, 0, 3}, {5, 0, 3}, {5, 0, 2}, {6, 0, 2}, {6, 0, 1}, {7, 0, 1}, // Blue to Red
  {7, 7, 7},{7, 2, 2},{3, 5, 7},  // White
};

byte myloc[3] = {2, 2, 2};
const byte cubetPath [50][3] PROGMEM = {  // cubet path
  {0, 0, 3}, {0, 1, 3}, {0, 2, 3}, {0, 3, 3}, {1, 3, 3}, {2, 3, 3}, {3, 3, 3}, {3, 2, 3}, {3, 1, 3}, {3, 0, 3}, {2, 0, 3}, {1, 0, 3}, {0, 0, 3},
  {0, 2, 0}, {0, 2, 1}, {0, 2, 2}, {0, 2, 3}, {1, 2, 3}, {2, 2, 3}, {3, 2, 3}, {3, 2, 2}, {3, 2, 1}, {3, 2, 0}, {2, 2, 0}, {1, 2, 0}, {0, 2, 0},
  {0, 0, 2}, {1, 0, 2}, {2, 0, 2}, {3, 0, 2}, {3, 1, 2}, {3, 2, 2}, {3, 3, 2}, {2, 3, 2}, {1, 3, 2}, {0, 3, 2}, {0, 2, 2}, {0, 1, 2}, {0, 0, 2},
  {2, 0, 1}, {1, 0, 1}, {0, 1, 1}, {0, 2, 1}, {1, 3, 1}, {2, 3, 1}, {3, 1, 1}, {3, 2, 1}, {2, 0, 1}
};
unsigned long start;

//////////////
SCD30 airSensor;
bool co2good;
int numspeed = 40;
int numstay= 400;

/////////////////////
int redPin = 10;
int greenPin = 11;
int bluePin = 12;
int buttonPin = 13;
int buttonState = 0;
int lastButtonState = 0;
int option = 0; // Variable to track the current option
#define COMMON_ANODE
int radiusChange = 0; // Variables used to control radius changes
////////////////////
//Skip remaining animation after button press
bool istemp=false;
bool ishum=false;
bool isco2=false;
////////////////


void setup() {
  Wire.begin();

  Serial.begin(9600);
  airSensor.begin(Wire); // Initialize the SCD30 sensor
    if (airSensor.begin() == false) {
    Serial.println("SCD30 not detected, please check the wiring!");
    while (1); // If the sensor is not detected, halt the program
  }
  //////////////////////////
  cube.begin();
  cube.setTextWrap(false);
  cube.setBrightness(brightness);
  initBall();
  /////////////////////////button pin
  pinMode(redPin, OUTPUT);
  pinMode(greenPin, OUTPUT);
  pinMode(bluePin, OUTPUT);  
  pinMode(buttonPin, INPUT_PULLUP); // Set the button as an input
  attachInterrupt(digitalPinToInterrupt(buttonPin),button111,CHANGE);
////////////////////////////
  
  delay(2000);
}


void loop() {
  //Switch between four animation modes according to button status
  switch(option){
    case 0:
  looptype1();
    //return;
    break;
    case 1:
  looptype2();
    //return;
    break;
    case 2:
    looptype3();
    //return;
    break;
    case 3:
    looptype4();
    //return;
    break;
  }

  

}





//LED coordinates and color settings
void LED(int x, int y, int z, unsigned int mycolor){
  if (z%2) cube.drawPixel((z+1)*8-x-1, y, GetColor(mycolor));
  else cube.drawPixel(x+(z*8),y, GetColor(mycolor));
}
void LED1(int z, int y, int x, unsigned int mycolor){
  if (z%2) cube.drawPixel((z+1)*8-x-1, y, GetColor(mycolor));
  else cube.drawPixel(x+(z*8),y, GetColor(mycolor));
}
void LED2(int z, int y, int x, byte red, byte green, byte blue){
  if (z%2) cube.drawPixel((z+1)*8-x-1, y, GetColor2(red,green,blue));
  else cube.drawPixel(x+(z*8),y, GetColor2(red,green,blue));
  //cube.show();
}
uint32_t GetColor(int thecolor) {
  byte myred = 36*pgm_read_byte_near(&color[thecolor][0]);
  byte mygreen = 36* pgm_read_byte_near(&color[thecolor][1]);
  byte myblue = 36*pgm_read_byte_near(&color[thecolor][2]);
  return cube.Color(myred,mygreen, myblue);
}

uint32_t GetColor2(byte red, byte green, byte blue) {
  byte myred = 36*pgm_read_byte_near(red);
  byte mygreen = 36* pgm_read_byte_near(green);
  byte myblue = 36*pgm_read_byte_near(blue);
  return cube.Color(myred,mygreen, myblue);
}

//clear all leds
void clearCube(){
cube.fill(Black);
}

void pause() {  // pause between animations
  clearCube();
  delay(500);
}

void showCube(int mytime) {
  delay(20 * mytime);
  clearCube();
}


//co2 animation
//////////////////////////////
void wave(int co2) {
  int wavespeed;
  if(co2>1500){
    mycolor =1;
    wavespeed=30;
  }else{
    mycolor =15;
    wavespeed=80;
  }
  int sinewavearray[8], addr, sinemult[8], colselect, rr = 0, gg = 0, bb = 15, addrt;
  int sinewavearrayOLD[8], select, subZ = -7, subT = 7, multi = 0;
  sinewavearray[0] = 0;
  sinemult[0] = 1;
  sinewavearray[1] = 1;
  sinemult[1] = 1;
  sinewavearray[2] = 2;
  sinemult[2] = 1;
  sinewavearray[3] = 3;
  sinemult[3] = 1;
  sinewavearray[4] = 4;
  sinemult[4] = 1;
  sinewavearray[5] = 5;
  sinemult[5] = 1;
  sinewavearray[6] = 6;
  sinemult[6] = 1;
  sinewavearray[7] = 7;
  sinemult[7] = 1;

  start = millis();

  while (millis() - start < 30000) {
    if( option!= 0 && !isco2){
      
      clearCube();
      return;
    }else if(option!= 3 && isco2){
      clearCube();
      //isco2=false;
      return;
    }
    for (addr = 0; addr < 8; addr++) {
      if (sinewavearray[addr] == 7) {
        sinemult[addr] = -1;
      }
      if (sinewavearray[addr] == 0) {
        sinemult[addr] = 1;
      }
      sinewavearray[addr] = sinewavearray[addr] + sinemult[addr];
    }
    if (sinewavearray[0] == 7) {
      select = random(3);
      if (select == 0) {
        rr = random(1, 16);
        gg = random(1, 16);
        bb = 0;
      }
      if (select == 1) {
        rr = random(1, 16);
        gg = 0;
        bb = random(1, 16);
      }
      if (select == 2) {
        rr = 0;
        gg = random(1, 16);
        bb = random(1, 16);
      }


    }

/////////////////////////////////////////////////
    for (addr = 0; addr < 8; addr++) {
      LED1(sinewavearrayOLD[addr], addr, 0, Black);
      LED1(sinewavearrayOLD[addr], 0, addr,Black);
      LED1(sinewavearrayOLD[addr], subT - addr, 7, Black);
      LED1(sinewavearrayOLD[addr], 7, subT - addr, Black);
      LED1(sinewavearray[addr], addr, 0, mycolor);
      LED1(sinewavearray[addr], 0, addr, mycolor);
      LED1(sinewavearray[addr], subT - addr, 7, mycolor);
      LED1(sinewavearray[addr], 7, subT - addr, mycolor);
      //cube.show();
    }

    for (addr = 1; addr < 7; addr++) {
      LED1(sinewavearrayOLD[addr + multi * 1], addr, 1, Black);
      LED1(sinewavearrayOLD[addr + multi * 1], 1, addr, Black);
      LED1(sinewavearrayOLD[addr + multi * 1], subT - addr, 6, Black);
      LED1(sinewavearrayOLD[addr + multi * 1], 6, subT - addr, Black);
      LED1(sinewavearray[addr + multi * 1], addr, 1, mycolor);
      LED1(sinewavearray[addr + multi * 1], 1, addr, mycolor);
      LED1(sinewavearray[addr + multi * 1], subT - addr, 6, mycolor);
      LED1(sinewavearray[addr + multi * 1], 6, subT - addr, mycolor);
      //cube.show();
    }

    for (addr = 2; addr < 6; addr++) {
      LED1(sinewavearrayOLD[addr + multi * 2], addr, 2, Black);
      LED1(sinewavearrayOLD[addr + multi * 2], 2, addr, Black);
      LED1(sinewavearrayOLD[addr + multi * 2], subT - addr, 5,Black);
      LED1(sinewavearrayOLD[addr + multi * 2], 5, subT - addr, Black);
      LED1(sinewavearray[addr + multi * 2], addr, 2, mycolor);
      LED1(sinewavearray[addr + multi * 2], 2, addr, mycolor);
      LED1(sinewavearray[addr + multi * 2], subT - addr, 5, mycolor);
      LED1(sinewavearray[addr + multi * 2], 5, subT - addr, mycolor);
      //cube.show();
    }
    for (addr = 3; addr < 5; addr++) {
      LED1(sinewavearrayOLD[addr + multi * 3], addr, 3, Black);
      LED1(sinewavearrayOLD[addr + multi * 3], 3, addr, Black);
      LED1(sinewavearrayOLD[addr + multi * 3], subT - addr, 4, Black);
      LED1(sinewavearrayOLD[addr + multi * 3], 4, subT - addr, Black);
      LED1(sinewavearray[addr + multi * 3], addr, 3, mycolor);
      LED1(sinewavearray[addr + multi * 3], 3, addr, mycolor);
      LED1(sinewavearray[addr + multi * 3], subT - addr, 4, mycolor);
      LED1(sinewavearray[addr + multi * 3], 4, subT - addr, mycolor);
      //cube.show();
    }
    /////////////////////////////////////////////////////
    for (addr = 0; addr < 8; addr++)
      sinewavearrayOLD[addr] = sinewavearray[addr];

    cube.show();
    //Skip remaining animation
    if( option!= 0 && !isco2){
      
      clearCube();
      return;
    }else if(option!= 3 && isco2){
      clearCube();
      //isco2=false;
      return;
    }
    
    delay(wavespeed);
  }
//Skip remaining animation
if( option!= 0 && !isco2){
      
      clearCube();
      return;
    }else if(option!= 3 && isco2){
      clearCube();
      //isco2=false;
      return;
    }

}


///////Numbers and letters animation

void num0(int mycolor){
  int z,y,x;
  for(int y=0;y<8;y++){
    for(x=2;x<6;x++){
      LED1(0, y, x, mycolor);
      LED1(7, y, x, mycolor);
    }
    for(z=1;z<7;z++){
      LED1(z, y, 1, mycolor);
      LED1(z, y, 6, mycolor);
    }
    cube.show();
    delay(numspeed);
    if(y!=7){
      clearCube();
    }
    //cube.show();
    
  }
  
  delay(numstay);
}
//////////////////////////////
void num1(int mycolor){
  for(int y=0;y<8;y++){
    for(int x1=1;x1<7;x1++){
      LED1(0, y, x1, mycolor);
    }
    for(int z1=1;z1<8;z1++){
      LED1(z1, y, 3, mycolor);
      LED1(z1, y, 4, mycolor);
    }
    LED1(5, y, 1, mycolor);
    LED1(6, y, 2, mycolor);
    cube.show();
    delay(numspeed);
    if(y!=7){
      clearCube();
    }
  }
  delay(numstay);
}
///////////////////////////

void num2(int mycolor){
  int z2[4]={1,2,3,4};
  int x2[4]={2,3,4,5};
 for(int y=0;y<8;y++){
    for(int x1=2;x1<7;x1++){
      LED1(0, y, x1, mycolor);
    }
    for(int i=0;i<4;i++){
      LED1(z2[i],y,x2[i],mycolor);
    }
    for(int z3=5;z3<7;z3++){
      LED1(z3,y,2,mycolor);
      LED1(z3,y,6,mycolor);
    }
    for(int x2=3;x2<6;x2++){
      LED1(7,y,x2,mycolor);
    }
    cube.show();
    delay(numspeed);
    if(y!=7){
      clearCube();
    }

  }
  delay(numstay);
}

////////////////////////////

void num3(int mycolor){
  for(int y=0;y<8;y++){
    for(int x1=3;x1<6;x1++){
      LED1(0,y,x1,mycolor);
      LED1(7,y,x1,mycolor);
    }
    for(int z1=1;z1<3;z1++){
      LED1(z1,y,6,mycolor);
    }
    for(int z2=5;z2<7;z2++){
      LED1(z2,y,6,mycolor);
    }
    for(int z3=3;z3<5;z3++){
      LED1(z3,y,5,mycolor);
    }
    LED1(1,y,2,mycolor);
    LED1(6,y,2,mycolor);
    LED1(3,y,4,mycolor);
    cube.show();
    delay(numspeed);
    if(y!=7){
      clearCube();
    }
  
  }
  delay(numstay);
}

//////////////////////////////////////////////

void num4(int mycolor){
  for(int y=0;y<8;y++){
    for(int z1=0;z1<8;z1++){
      LED1(z1,y,4,mycolor);
    }
    for(int z2=3;z2<8;z2++){
      LED1(z2,y,1,mycolor);
    }
    for(int x1=1;x1<7;x1++){
      LED1(3,y,x1,mycolor);
    }
    cube.show();
    delay(numspeed);
    if(y!=7){
      clearCube();
    }

  }
  delay(numstay);
}

///////////////////////////////////

void num5(int mycolor){
  for(int y=0;y<8;y++){
    for(int x1=2;x1<7;x1++){
      LED1(7,y,x1,mycolor);
    }
    for(int x2=2;x2<6;x2++){
      LED1(4,y,x2,mycolor);
      LED1(0,y,x2,mycolor);
    }
    for(int z1=5;z1<7;z1++){
      LED1(z1,y,2,mycolor);
    }
    for(int z2=1;z2<4;z2++){
      LED1(z2,y,6,mycolor);
    }
    cube.show();
    delay(numspeed);
    if(y!=7){
      clearCube();
    }
    
  }
  delay(numstay);

}
////////////////////

void num6(int mycolor){
 for(int y=0;y<8;y++){
    for(int x1=2;x1<7;x1++){
      LED1(0,y,x1,mycolor);
      LED1(4,y,x1,mycolor);
      LED1(7,y,x1,mycolor);
    }
    for(int z1=1;z1<4;z1++){
      LED1(z1,y,2,mycolor);
    }
    for(int z2=1;z2<7;z2++){
      LED1(z2,y,2,mycolor);
    }
    for(int z2=0;z2<5;z2++){
      LED1(z2,y,6,mycolor);
    }
    cube.show();
    delay(numspeed);
    if(y!=7){
      clearCube();
    }
    //cube.show();
  }
  delay(numstay);
}

//////////////
void num7(int mycolor){
  int z1[7]={0,0,0,0,2,4,6};
  int z2[7]={0,0,0,2,4,6,8};
  for(int y=0;y<8;y++){
    for(int x1=2;x1<7;x1++){
      LED1(7,y,x1,mycolor);
    }
    for(int x2=3;x2<7;x2++){
      for(int z=z1[x2];z<z2[x2];z++){
        LED1(z,y,x2,mycolor);
      }
    }
    cube.show();
    delay(numspeed);
    if(y!=7){
      clearCube();
    }
    //cube.show();
  }
  delay(numstay);
}
/////////////////
void num8(int mycolor){
  int z[6]={6,6,5,5,3,3};
  int x[6]={6,1,5,2,5,2,};
  for(int y=0;y<8;y++){
    for(int x1=2;x1<6;x1++){
      LED1(0,y,x1,mycolor);
      LED1(7,y,x1,mycolor);
    }
    for(int z1=1;z1<3;z1++){
      LED1(z1,y,1,mycolor);
      LED1(z1,y,6,mycolor);
    }
    for(int x2=3;x2<5;x2++){
      LED1(4,y,x2,mycolor);
    }
    for(int i=0;i<6;i++){
      LED1(z[i],y,x[i],mycolor);
    }
    cube.show();
    delay(numspeed);
    if(y!=7){
      clearCube();
    }
  }
  //cube.show();
  delay(numstay);
}
/////////////
void num9(int mycolor){
  for(int y=0;y<8;y++){
    for(int x1=3;x1<6;x1++){
      LED1(0,y,x1,mycolor);
      LED1(3,y,x1,mycolor);
      LED1(7,y,x1,mycolor);
    }
    for(int z1=1;z1<7;z1++){
      LED1(z1,y,6,mycolor);
    }
    for(int z2=4;z2<7;z2++){
      LED1(z2,y,2,mycolor);
    }
    LED1(1,y,2,mycolor);
    cube.show();
    delay(numspeed);
    if(y!=7){
      clearCube();
    }
  }
  //cube.show();
  delay(numstay);
}
/////////////
void T(int mycolor){
  for(int y=0;y<8;y++){
    for(int x1=1;x1<8;x1++){
      LED1(7,y,x1,mycolor);
    }
    for(int z1=0;z1<7;z1++){
      LED1(z1,y,4,mycolor);
    }
    cube.show();
    delay(numspeed);
    if(y!=7){
      clearCube();
    }
    
  }
  delay(numstay);
}
///////////////////
void U(int mycolor){
  for(int y=0;y<8;y++){
    for(int x1=2;x1<6;x1++){
      LED1(0,y,x1,mycolor);
    }
    for(int z1=1;z1<8;z1++){
      LED1(z1,y,1,mycolor);
      LED1(z1,y,6,mycolor);
    }
    cube.show();
    delay(numspeed);
    if(y!=7){
      clearCube();
    }
  }
  delay(numstay);
}
///////////////////////
void M(int mycolor){
  for(int y=0;y<8;y++){
    for(int z1=0;z1<8;z1++){
      LED1(z1,y,1,mycolor);
      LED1(z1,y,7,mycolor);
    }
    for(int z2=3;z2<5;z2++){
      LED1(z2,y,4,mycolor);
    }
    LED1(6,y,2,mycolor);
    LED1(6,y,6,mycolor);
    LED1(5,y,3,mycolor);
    LED1(5,y,5,mycolor);

    cube.show();
    delay(numspeed);
    if(y!=7){
      clearCube();
    }
    
  }
  delay(numstay);
}
///////////////////////////////
void P(int mycolor){
  for(int y=0;y<8;y++){
    for(int z1=0;z1<8;z1++){
      LED1(z1,y,1,mycolor);
    }
    for(int x1=1;x1<5;x1++){
      LED1(2,y,x1,mycolor);
      LED1(7,y,x1,mycolor);
    }
    LED1(6,y,5,mycolor);
    LED1(3,y,5,mycolor);
    LED1(4,y,6,mycolor);
    LED1(5,y,6,mycolor);
    cube.show();
    delay(numspeed);
    if(y!=7){
      clearCube();
    }
  }
  delay(numstay);
}
///////////////////////////
void H(int mycolor){
  for(int y=0;y<8;y++){
    for(int z1=0;z1<8;z1++){
      LED1(z1,y,2,mycolor);
      LED1(z1,y,6,mycolor);
    }
    for(int x1=2;x1<7;x1++){
      LED1(4,y,x1,mycolor);
    }
    cube.show();
    delay(numspeed);
    if(y!=7){
      clearCube();
    }
  
  }
  delay(numstay);
}
/////////////////////////
void C(int mycolor){
  for(int y=0;y<8;y++){
    for(int x1=3;x1<6;x1++){
      LED1(0,y,x1,mycolor);
      LED1(7,y,x1,mycolor);
    }
    for(int x1=2;x1<6;x1++){
      LED1(x1,y,1,mycolor);
    }
    LED1(1,y,2,mycolor);
    LED1(1,y,6,mycolor);
    LED1(6,y,2,mycolor);
    LED1(6,y,6,mycolor);
    cube.show();
    delay(numspeed);
    if(y!=7){
      clearCube();
    }
    
  }
  delay(numstay);
}
///////////////////////
void colon(int mycolor){
  for(int y=0;y<8;y++){
    for(int z1=5;z1<7;z1++){
      for(int x1=3;x1<5;x1++){
        LED1(z1,y,x1,mycolor);
      }
    }
    for(int z1=1;z1<3;z1++){
      for(int x1=3;x1<5;x1++){
        LED1(z1,y,x1,mycolor);
      }
    }
    cube.show();
    delay(numspeed);
    if(y!=7){
      clearCube();
    }
   
  }
  delay(numstay);
}
//////////////////////////////
void percentage(int mycolor){
  for(int x=7;x>-1;x--){
    for(int z1=5;z1<7;z1++){
      for(int y1=1;y1<3;y1++){
        LED1(z1,y1,x,mycolor);
      }
    }
    for(int z1=1;z1<3;z1++){
      for(int y1=5;y1<7;y1++){
        LED1(z1,y1,x,mycolor);
      }
    }
    for(int z1=2;z1<4;z1++){
      LED1(z1,3,x,mycolor);
    }
    for(int z1=4;z1<6;z1++){
      LED1(z1,4,x,mycolor);
    }
    LED1(0,1,x,mycolor);
    LED1(1,2,x,mycolor);
    LED1(6,5,x,mycolor);
    LED1(7,6,x,mycolor);

    cube.show();
    delay(numspeed);
    if(x!=0){
      clearCube();
    }
  
  }
  delay(numstay);
}
////////////////////
void exclamation(int mycolor){
  for(int x=7;x>-1;x--){
    for(int z1=3;z1<8;z1++){
      LED1(z1,3,x,mycolor);
      LED1(z1,4,x,mycolor);
    }
    for(int z1=0;z1<2;z1++){
      for(int y1=3;y1<5;y1++){
        LED1(z1,y1,x,mycolor);
      }
    }
    cube.show();
    delay(numspeed);
    if(x!=0){
      clearCube();
    }

  }
  delay(numstay);
}
/////////////////
void degree(int mycolor){
  for(int x=7;x>-1;x--){
    for(int z1=6;z1<8;z1++){
      for(int y1=0;y1<2;y1++){
        LED1(z1,y1,x,mycolor);
      }
    }
    for(int z1=1;z1<6;z1++){
      LED1(z1,2,x,mycolor);
    }
    for(int y1=3;y1<6;y1++){
      LED1(0,y1,x,mycolor);
      LED1(6,y1,x,mycolor);
    }
    LED1(1,6,x,mycolor);
    LED1(5,6,x,mycolor);
    cube.show();
    delay(numspeed);
    if(x!=0){
      clearCube();
    }

  }
  delay(numstay);
}
///////////////////
void E(int mycolor){
  for(int y=0;y<8;y++){
    for(int x=1;x<7;x++){
      LED1(0,y,x,mycolor);
      LED1(4,y,x,mycolor);
      LED1(7,y,x,mycolor);
    }
    for(int z=0;z<8;z++){
      LED1(z,y,1,mycolor);
    }
    cube.show();
    delay(numspeed);
    if(y!=7){
      clearCube();
    }

  }
  delay(numstay);
}

//////////Read sensor co2 data and display digital animation based on the data
///////////////////
void co2data(int co2){
  String co2data=String(co2);
  //////number of digits
  int numlength= co2data.length();
  Serial.println(co2data);
  Serial.println(numlength);
  if(co2>1500){
    mycolor =1;
  }else{
    mycolor =15;
  }
  C(mycolor);
  num0(mycolor);
  num2(mycolor);
  colon(mycolor);
  numspeed=30;
//Skip remaining animation
  for(int i=0;i<co2data.length();i++){
    if( option!= 0 && !isco2){
  
      clearCube();
      return;
    }else if(option!= 3 && isco2){
      clearCube();
      
      return;
    }
    ////Numeric animation showing each digit in sequence
    char Digit= co2data.charAt(i);
    Serial.println(Digit);
    switch(Digit){
      case '0':
      num0(mycolor);
      break;
      case '1':
      num1(mycolor);
      break;
      case '2':
      num2(mycolor);
      break;
      case '3':
      num3(mycolor);
      break;
      case '4':
      num4(mycolor);
      break;
      case '5':
      num5(mycolor);
      break;
      case '6':
      num6(mycolor);
      break;
      case '7':
      num7(mycolor);
      break;
      case '8':
      num8(mycolor);
      break;
      case '9':
      num9(mycolor);
      break;
      default:
      break;
    }


    //delay(450);
    
  }
    

  
}
////////////Read sensor temp data and display digital animation based on the data
void Tempdata(float temp){
  String tempdata=String(temp,0);
  int numlength= tempdata.length();
  Serial.println(tempdata);
  Serial.println(numlength);
  /////number animation color
  if(temp>=20){
    mycolor =1;
  }else if(10>temp>=15){
    mycolor =44;
  }else if(5>temp>=10){
    mycolor =45;
  }else if(temp<=5){
    mycolor =29;
  }
  T(mycolor);
  E(mycolor);
  M(mycolor);
  P(mycolor);
  colon(mycolor);
  ////skip
  for(int i=0;i<tempdata.length();i++){
    if( option!= 0 && !istemp){
  
      return;
    }else if(option!= 1 && istemp){
      
      return;
    }

    ///////////Numeric animation showing each digit in sequence
    char Digit= tempdata.charAt(i);
    Serial.println(Digit);
    switch(Digit){
      case '0':
      num0(mycolor);
      break;
      case '1':
      num1(mycolor);
      break;
      case '2':
      num2(mycolor);
      break;
      case '3':
      num3(mycolor);
      break;
      case '4':
      num4(mycolor);
      break;
      case '5':
      num5(mycolor);
      break;
      case '6':
      num6(mycolor);
      break;
      case '7':
      num7(mycolor);
      break;
      case '8':
      num8(mycolor);
      break;
      case '9':
      num9(mycolor);
      break;
      default:
      break;
    }
    
    delay(450);
  }
  delay(500);
  clearCube();
}
//////////////////////////////sun animation
struct Ball {
  int Bx, By, Bz;
  int vx, vy, vz;
} ball;

int calculateRadius() {
  // The radius changes periodically between 1 and 4
  float radius = 1.0 + (sin(radiusChange * 0.2) + 1.0) * 1.5; // Adjust formulas to change amplitude and offset

 
  radius = max(1.0, min(radius, 4.0));
  return static_cast<int>(radius);
}

void initBall() {
  // The center point of the randomly initialized ball is within the internal 4x4x4 matrix
  ball.Bx = random(2, 6); 
  ball.By = random(2, 6); 
  ball.Bz = random(2, 6); 

  // Initialize ball speed
  ball.vx = random(-1, 2); 
  ball.vy = random(-1, 2);
  ball.vz = random(-1, 2);
}
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

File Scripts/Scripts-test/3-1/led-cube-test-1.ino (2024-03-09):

#define myLayer 2
#include <Adafruit_GFX.h>
#include <Adafruit_NeoMatrix.h>
#include <Adafruit_NeoPixel.h>
#include <Wire.h>

#include <SparkFun_SCD30_Arduino_Library.h> // Include the SCD30 library
#define PIN 6
//////////////////////////////////
#define CPU_HZ 48000000
#define TIMER_PRESCALER_DIV 1024



/////////////////////////////////////
int frequencyHz =60;
void startTimer(int frequencyHz);
void setTimerFrequency(int frequencyHz);
void TC3_Handler();
//////////////////////////////////////
volatile uint16_t mymatrix[16][8];  // color of each LED in the matrix
int brightness = 80;  // set brightness here  0-256 with 10 for easy on eyes

Adafruit_NeoMatrix cube = Adafruit_NeoMatrix(8, 8, 8, 1, PIN,
                          NEO_MATRIX_TOP     + NEO_MATRIX_LEFT +
                          NEO_MATRIX_COLUMNS + NEO_MATRIX_ZIGZAG,
                          NEO_RGB            + NEO_KHZ800);



#define White 43
#define Black 0
#define Red 1
#define Orange 4
#define Yellow 9
#define Green 15
#define Aqua 20
#define Blue 29
#define Purple 34
uint32_t mycolor;
const byte color [44][3] PROGMEM = {  // the color pallette table
  {0, 0, 0}, //Black
  {7, 0, 0}, {7, 1, 0}, {6, 1, 0}, {6, 2, 0}, {5, 2, 0}, {5, 3, 0}, {4, 3, 0}, {4, 4, 0}, {3, 4, 0}, {3, 5, 0}, {2, 5, 0}, {2, 6, 0}, {1, 6, 0}, {1, 7, 0}, // Red to Green
  {0, 7, 0}, {0, 7, 1}, {0, 6, 1}, {0, 6, 2}, {0, 5, 2}, {0, 5, 3}, {0, 4, 3}, {0, 4, 4}, {0, 3, 4}, {0, 3, 5}, {0, 2, 5}, {0, 2, 6}, {0, 1, 6}, {0, 1, 7}, // Green to Blue
  {0, 0, 7}, {1, 0, 7}, {1, 0, 6}, {2, 0, 6}, {2, 0, 5}, {3, 0, 5}, {3, 0, 4}, {4, 0, 4}, {4, 0, 3}, {5, 0, 3}, {5, 0, 2}, {6, 0, 2}, {6, 0, 1}, {7, 0, 1}, // Blue to Red
  {7, 7, 7},  // White
};

byte myloc[3] = {2, 2, 2};
const byte cubetPath [50][3] PROGMEM = {  // cubet path
  {0, 0, 3}, {0, 1, 3}, {0, 2, 3}, {0, 3, 3}, {1, 3, 3}, {2, 3, 3}, {3, 3, 3}, {3, 2, 3}, {3, 1, 3}, {3, 0, 3}, {2, 0, 3}, {1, 0, 3}, {0, 0, 3},
  {0, 2, 0}, {0, 2, 1}, {0, 2, 2}, {0, 2, 3}, {1, 2, 3}, {2, 2, 3}, {3, 2, 3}, {3, 2, 2}, {3, 2, 1}, {3, 2, 0}, {2, 2, 0}, {1, 2, 0}, {0, 2, 0},
  {0, 0, 2}, {1, 0, 2}, {2, 0, 2}, {3, 0, 2}, {3, 1, 2}, {3, 2, 2}, {3, 3, 2}, {2, 3, 2}, {1, 3, 2}, {0, 3, 2}, {0, 2, 2}, {0, 1, 2}, {0, 0, 2},
  {2, 0, 1}, {1, 0, 1}, {0, 1, 1}, {0, 2, 1}, {1, 3, 1}, {2, 3, 1}, {3, 1, 1}, {3, 2, 1}, {2, 0, 1}
};
unsigned long start;

//////////////
SCD30 airSensor;
bool co2good;
int numspeed = 40;
int numstay= 400;

/////////////////////
int redPin = 10;
int greenPin = 11;
int bluePin = 12;
int buttonPin = 13;
int buttonState = 0;
int lastButtonState = 0;
int option = 0; // Variable to track the current option
#define COMMON_ANODE
////////////////////



void setup() {
  Wire.begin();

  Serial.begin(9600);
  airSensor.begin(Wire); // Initialize the SCD30 sensor
    if (airSensor.begin() == false) {
    Serial.println("SCD30 not detected, please check the wiring!");
    while (1); // If the sensor is not detected, halt the program
  }
  //////////////////////////
  cube.begin();
  cube.setTextWrap(false);
  cube.setBrightness(brightness);
  /////////////////////////
  pinMode(redPin, OUTPUT);
  pinMode(greenPin, OUTPUT);
  pinMode(bluePin, OUTPUT);  
  pinMode(buttonPin, INPUT_PULLUP); // Set the button as an input
////////////////////////////


  startTimer(10);

  

  
  delay(2000);
}



void loop() {
  buttonState = digitalRead(buttonPin);
  if (buttonState != lastButtonState) {
    if (buttonState == LOW) { // Check if button is pressed
      option++; // Increment option
      if (option > 3) option = 0; // Cycle back to the first option after the last one
      
      // Change color based on the current option and print a message to the Serial Monitor
      switch (option) {
        case 0:
          setColor(255, 0, 0); // red
          Serial.println("Option a selected: Red");
          looptype1();
        break;
        case 1:
          setColor(0, 255, 0); // green
          Serial.println("Option b selected: Green");
          looptype2();
          break;
        case 2:
          setColor(0, 0, 255); // blue
          Serial.println("Option c selected: Blue");
          looptype3();
          break;
        case 3:
          setColor(252, 226, 0); // yellow
          Serial.println("Option d selected: Yellow");
          looptype4();
          break;
      }
    }
    delay(150); // Debounce delay
  }
  lastButtonState = buttonState; // Save the last button state


  // int co2= airSensor.getCO2();
  // delay(100);
  // co2data(co2);
  // clearCube();
  // delay(500);
  // sinwaveTwo(co2);
  // clearCube();
  // delay(500);
  // float tump= airSensor.getTemperature();
  // delay(100);
  // Tumpdata(tump);
  // delay(500);
  // clearCube();
  // delay(500);
  // //烟花
  // clearCube();
  // float hum= airSensor.getHumidity();
  // delay(100);
  // Humdata(hum);
  // clearCube();
  // delay(500);
  // rain(hum);
  // clearCube();
  // delay(500);


}

////////////////////////////////////////////////////
void setTimerFrequency(int frequencyHz) {
  int compareValue = (CPU_HZ / (TIMER_PRESCALER_DIV * frequencyHz)) - 1;
  TcCount16* TC = (TcCount16*) TC3;
  // Make sure the count is in a proportional position to where it was
  // to prevent any jitter or disconnect when changing the compare value.
  TC->COUNT.reg = map(TC->COUNT.reg, 0, TC->CC[0].reg, 0, compareValue);
  TC->CC[0].reg = compareValue;
  Serial.println(TC->COUNT.reg);
  Serial.println(TC->CC[0].reg);
  while (TC->STATUS.bit.SYNCBUSY == 1);
}

void startTimer(int frequencyHz) {
  REG_GCLK_CLKCTRL = (uint16_t) (GCLK_CLKCTRL_CLKEN | GCLK_CLKCTRL_GEN_GCLK0 | GCLK_CLKCTRL_ID_TCC2_TC3) ;
  while ( GCLK->STATUS.bit.SYNCBUSY == 1 ); // wait for sync

  TcCount16* TC = (TcCount16*) TC3;

  TC->CTRLA.reg &= ~TC_CTRLA_ENABLE;
  while (TC->STATUS.bit.SYNCBUSY == 1); // wait for sync

  // Use the 16-bit timer
  TC->CTRLA.reg |= TC_CTRLA_MODE_COUNT16;
  while (TC->STATUS.bit.SYNCBUSY == 1); // wait for sync

  // Use match mode so that the timer counter resets when the count matches the compare register
  TC->CTRLA.reg |= TC_CTRLA_WAVEGEN_MFRQ;
  while (TC->STATUS.bit.SYNCBUSY == 1); // wait for sync

  // Set prescaler to 1024
  TC->CTRLA.reg |= TC_CTRLA_PRESCALER_DIV1024;
  while (TC->STATUS.bit.SYNCBUSY == 1); // wait for sync

  setTimerFrequency(frequencyHz);

  // Enable the compare interrupt
  TC->INTENSET.reg = 0;
  TC->INTENSET.bit.MC0 = 1;

  NVIC_EnableIRQ(TC3_IRQn);

  TC->CTRLA.reg |= TC_CTRLA_ENABLE;
  while (TC->STATUS.bit.SYNCBUSY == 1); // wait for sync
}

void TC3_Handler() {
  TcCount16* TC = (TcCount16*) TC3;
  // If this interrupt is due to the compare register matching the timer count
  // we toggle the LED.
  if (TC->INTFLAG.bit.MC0 == 1) {
    TC->INTFLAG.bit.MC0 = 1;
    cube.show();
    //button111();
  }
}
////////////////////////////////////////////////////
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

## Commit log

2024-03-01 upload pcb
2024-03-01 upload case design
2024-03-01 upload PCB 3d model
2024-03-08 Create button_rgb.ino
    Button
2024-03-08 Create led-cube-test-1.ino
    main
2024-03-09 Update led-cube-test-1.ino
    3/9-update button code
2024-03-18 upload 3d parts and cutting components
    [16-Pin Header - Female - 2.54mm v1.obj, FEATHER_M0_BASIC_PROTO v2.obj, RGB_push_button_16mm.obj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]
2024-03-18 upload schematics and cam files
    [Led_Cube v25.brd, Led_Cube_v15.sch]
2024-03-18 rearranged files
    [16-Pin Header - Female - 2.54mm v1.obj, FEATHER_M0_BASIC_PROTO v2.obj, Led_Cube v25.brd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]

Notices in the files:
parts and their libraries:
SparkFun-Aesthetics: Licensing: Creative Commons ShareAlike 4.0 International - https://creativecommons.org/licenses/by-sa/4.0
